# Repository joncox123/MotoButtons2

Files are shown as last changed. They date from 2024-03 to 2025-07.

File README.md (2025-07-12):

# MotoButtons 2
### MotoButtons 2 has reached the initial 2.0 release and is ready for users to build their own unit. You can build this either for a commercial, 5-way IP68 joystick, the part costs $75 USD + shipping, or with the original $2.50 USD Adafruit 504 5-way joystick (as in MotoButtons Lite). However, construction is much easier either way because of the 3D printed Nylon case.

**If you have developed different or improved 3D printed case designs, please let me know via the Issues and I can either link to them here or add them to this repository.**

Please submit any bug reports via the Issues tab on this GitHub repository page.

### Welcome to MotoButtons 2, the low-cost, waterproof, DIY Bluetooth motorcycle controller. Version 2 features many upgrades over [the original](https://github.com/joncox123/MotoButtons):
- 3D printed case with handlebar mount
- Separate RGB LED for indicating modes and status
- Commercial, IP68 5-way (or 4-way) castle joystick ($75 USD + shipping)
  -  or the original $2.50 USD 5-way Adafruit joystick [see alternative case design](./CaseAdafruitJoystick/README.md)
- Three pushbuttons

The target price to order all parts, including the case, is approximately $80 to $100 excluding shipping costs. The main variable is the cost and quality of the 3D printed case. However, the most expensive part is the IP68 rated 5-way joystick. The cheapest available is from Ruffy Controls, although industry prices for similar parts vary from $45 to beyond $300. Lastly, the least expensive service for 3D printing is [Craftcloud](https://craftcloud3d.com/).

## User Documentation
Please see the **[User's Guide](./UsersGuide/README.md)** for instructions on how to use your MotoButtons 2.

## Assembly Steps

[1] Order your 3D printed case by uploading the three CAD STEP files to [Craftcloud](https://craftcloud3d.com/). Choose the Nylon SLA material, not filament PLA.
  - For the Ruffy HS IP68 joystick, [upload these CAD STEP files](./Case/Parts). **NOTE: please wait for a revision of this case that includes 6 screws for the lid and a thicker handlebar clamp before ordering. The Adafruit case version has already been revised.**
  - For the low-cost, Adafruit $2.50 USD 5-way joystick, use [these STEP files](CaseAdafruitJoystick/README.md) for the case instead.

[2] Order the parts from Digikey or Mouser:
  - For the commercial, IP68 5-way joystick from Ruffy Controls, [order from Digikey](https://www.digikey.com/short/hzjjppm1). These parts are also listed in the [Bill of Materials](./Parts/BOM.csv). Note, due to shipping costs, it is cheaper to order several HS joysticks from Ruffy Controls at once. I recommend ordering one for each bike, or organize a group buy on a forum.
  - Using the $2.50 Adafruit 504 5-way joystick (no additional shipping costs), [from Mouser](https://www.mouser.com/ProjectManager/ProjectDetail.aspx?AccessID=e6513e64c0). See the [Bill of Materials](CaseAdafruitJoystick/BOM.csv).

[3] Read the [wiring diagram and construction guide](./ConstructionGuide/README.md) to assemble your MotoButtons 2 after obtaining the parts and the case.

[4] Upload the software to the microcontroller using a USB-C cable and the Arduino program. See [this guide](./Programming/README.md) for detailed instructions.

### A case for the Ruffy 4/5-way joystick
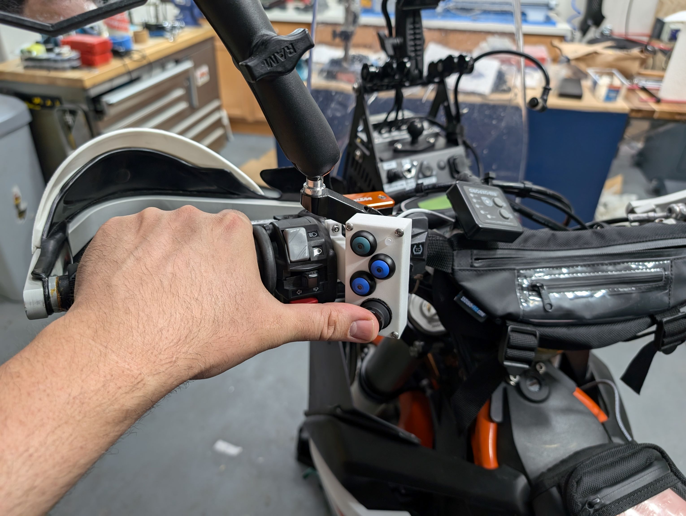
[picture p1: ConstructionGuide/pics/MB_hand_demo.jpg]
Completed unit mounted to bike

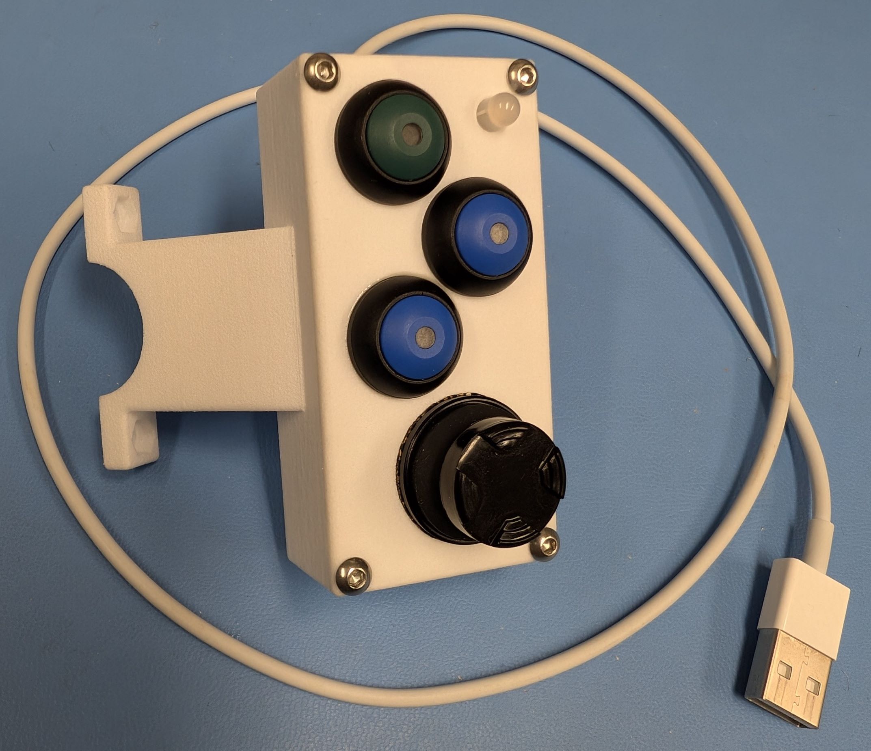
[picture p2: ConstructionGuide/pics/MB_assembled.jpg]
Assembled unit on electrical bench

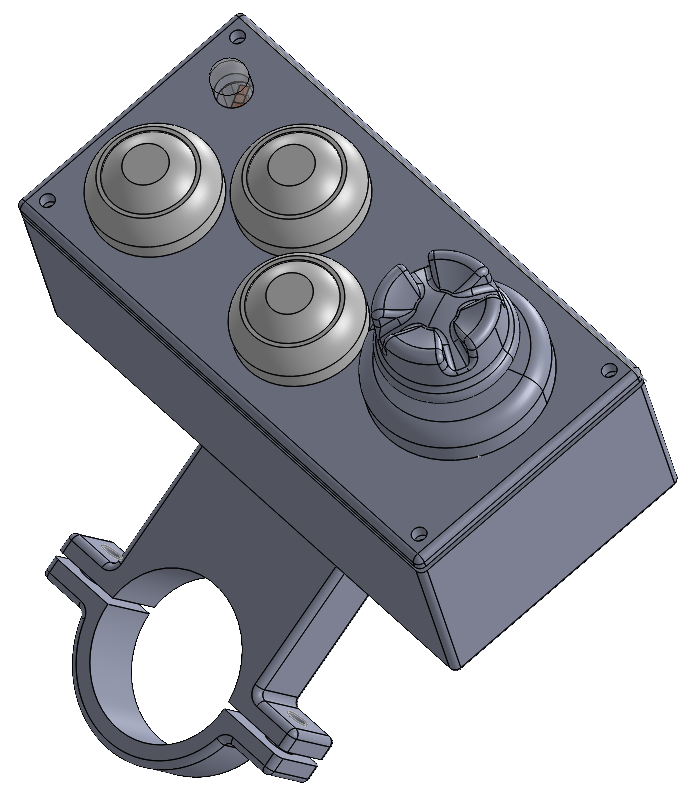
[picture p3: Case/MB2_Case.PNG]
3D Printed Case Model


### A case for the Adafruit 504 $2.50 USD 5-way joystick
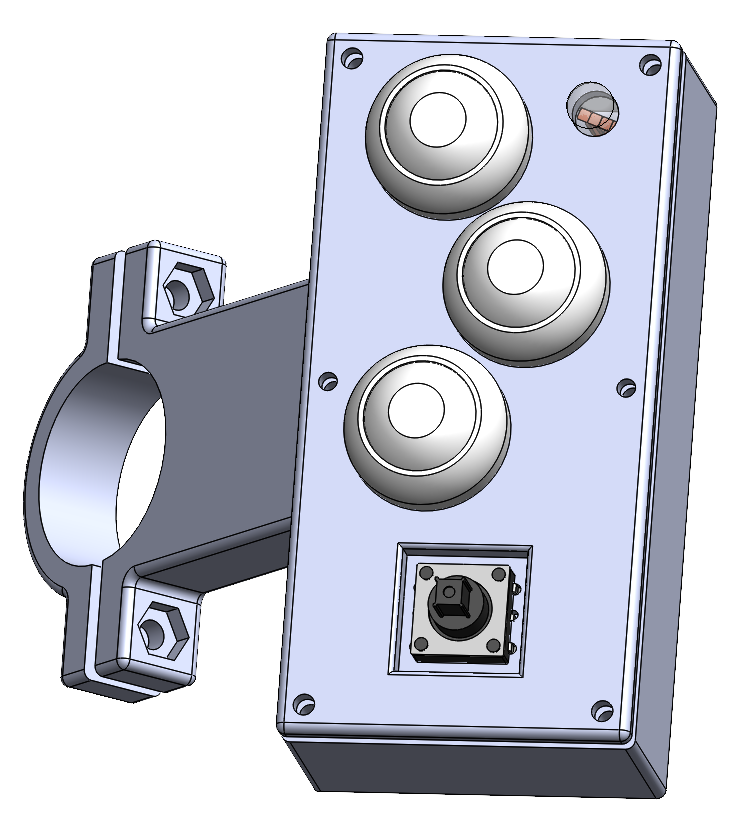
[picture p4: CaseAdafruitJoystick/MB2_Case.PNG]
Low-cost 3D Printed Case Model


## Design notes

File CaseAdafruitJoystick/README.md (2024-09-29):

# An alternative case that uses the very low cost, 5-way Adafruit 504 joystick

[Download the CAD STEP files](Parts) to upload to your 3D printing service.

Case for Adafruit low cost joystick

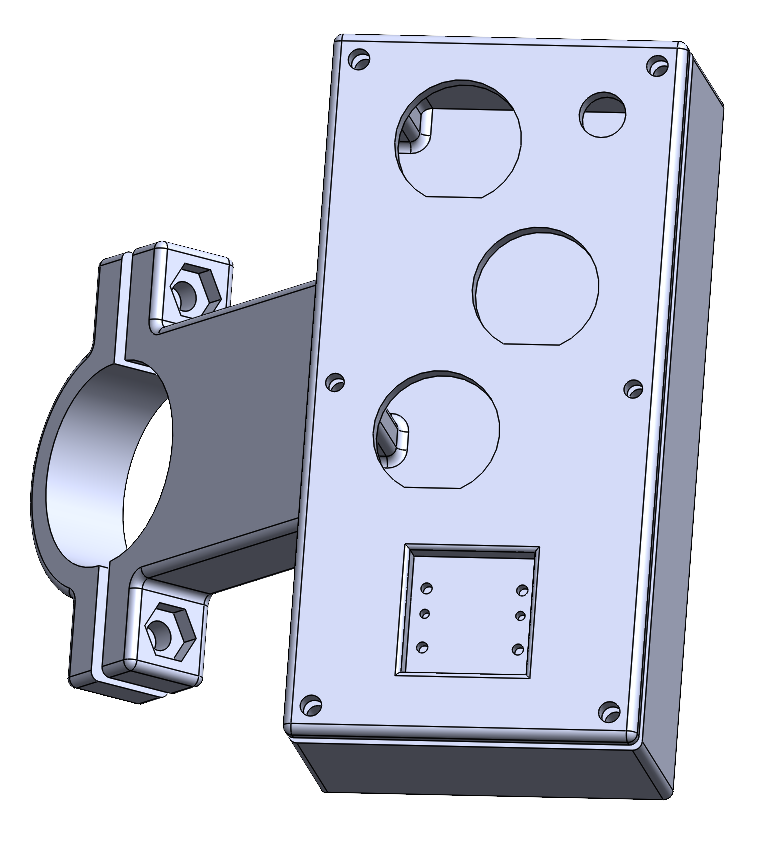
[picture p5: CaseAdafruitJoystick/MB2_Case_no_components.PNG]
Case for Adafruit low cost joystick


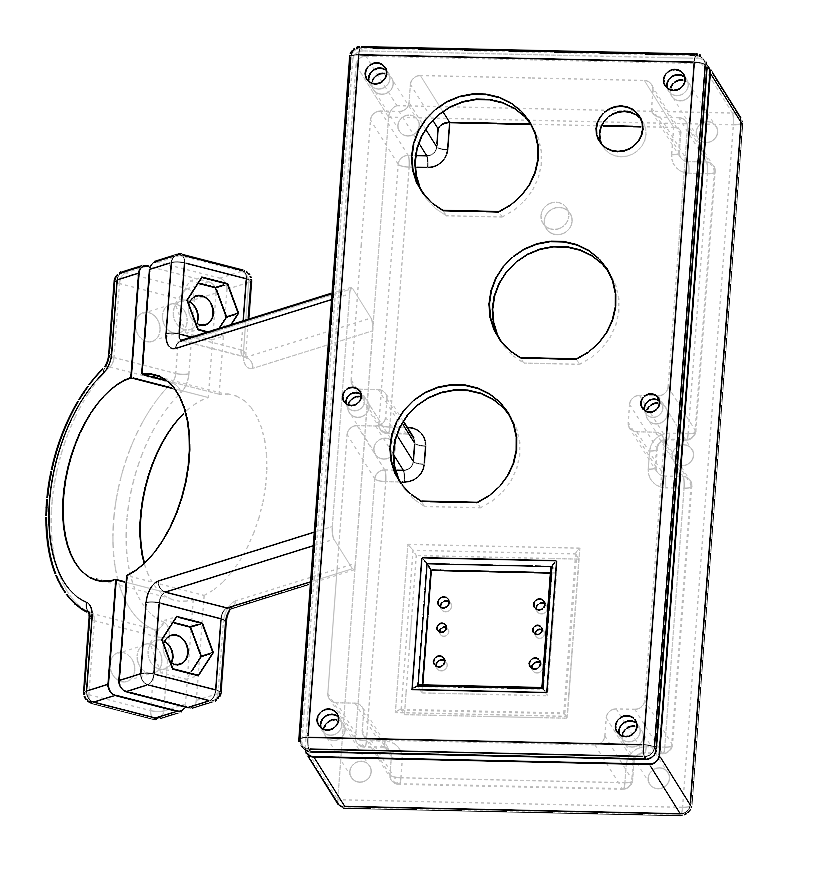
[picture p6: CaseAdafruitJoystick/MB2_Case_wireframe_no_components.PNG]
Case for Adafruit low cost joystick


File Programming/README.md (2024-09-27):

## Upload the Microcontroller Software
The easiest way to do this would be with a custom installer. However, that work is not yet done, so you will need to [download the Arduino IDE](https://www.arduino.cc/en/software), install the support package for the microcontroller, and then upload via a USB cable. The installation steps are [described here.](https://wiki.seeedstudio.com/XIAO_BLE/#getting-started)

First, open the Arduino IDE and then open Preferences in the File menu. Paste the URL (https://files.seeedstudio.com/arduino/package_seeeduino_boards_index.json) to the microcontroller board support package into the "Additional board managers URLs" text field. Click OK. 

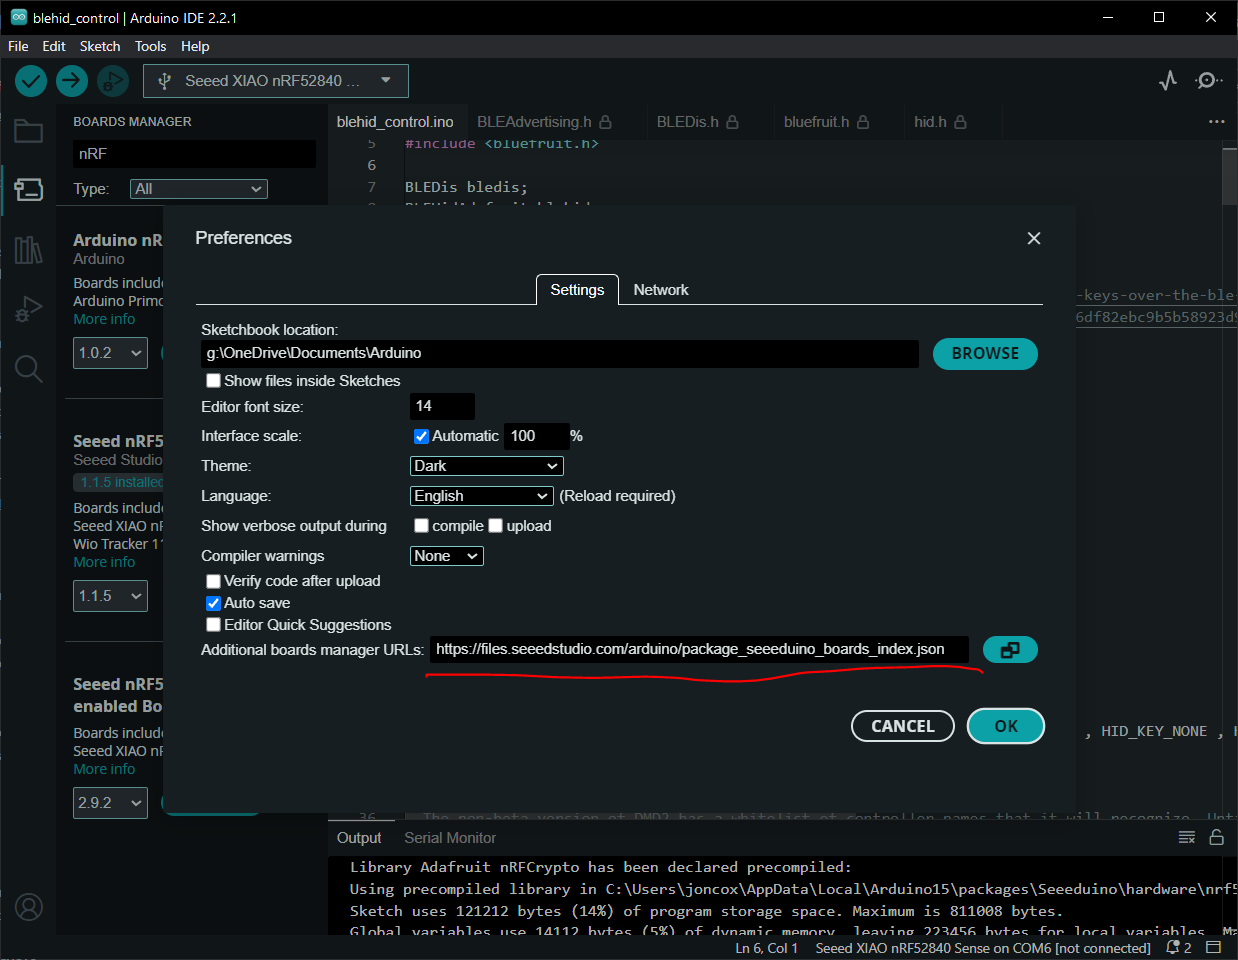
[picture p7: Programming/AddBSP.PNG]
add Seeed BSP


Second, install the Seeed nRF Boards package by clicking on the side button that is second from the top, to open the Board Manager. Type "nRF" into the search field at the top and install the "Seeed nRF52 Boards" package. 

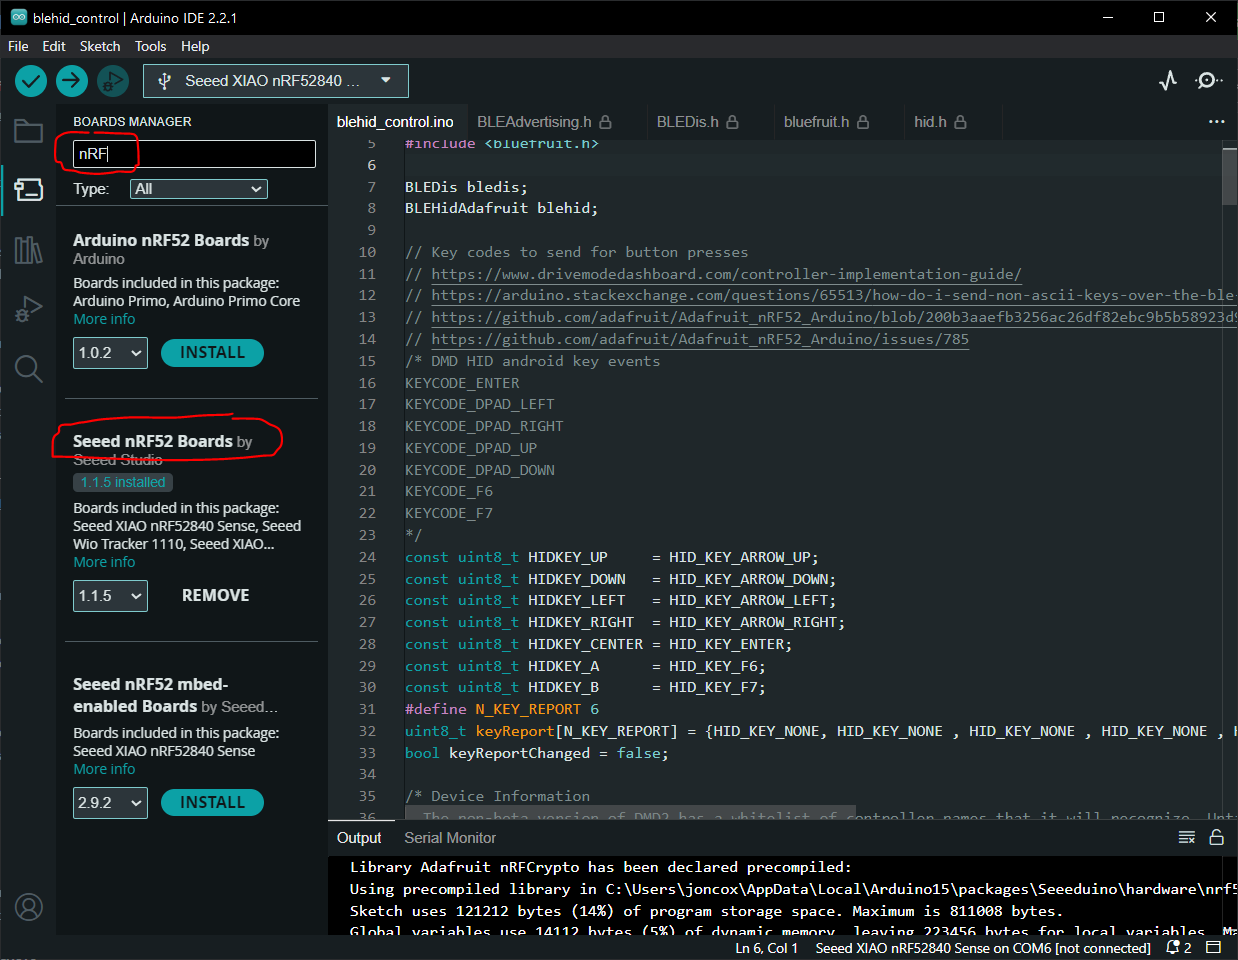
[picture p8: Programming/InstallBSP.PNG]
install Seeed BSP


Third, [download the source code file](../ArduinoCode/MotoButtons2.ino) and open in the Arduino IDE. Attach the microcontroller via a USB-C cable. Select the board that you just attached with the drop down box in the upper toolbar. It should say "Seeed XIAO nRF52840".

Finally, click the upload button!

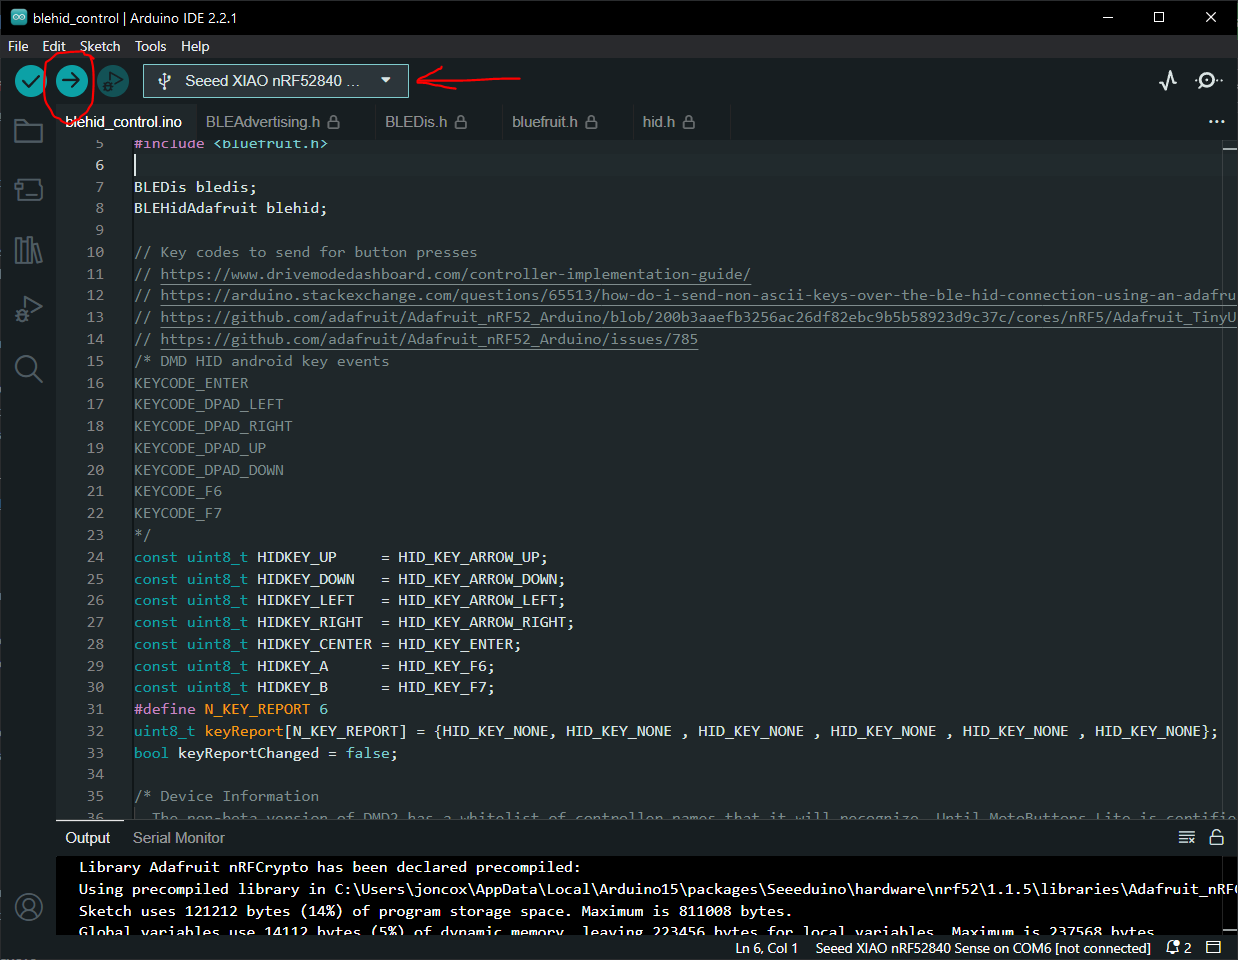
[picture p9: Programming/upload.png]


## Updating the Software for Future Releases
To update the software again, you need to open the case and connect the USB-C port to your computer. Launch the Arduino IDE and open the new source code file. However, there is a bug in the microcontroller's DFU (Device Firmware Update) bootloader that sometimes prevents new software from being uploaded unless a special reset procedure is followed. 

If you try to upload new software and you either get an error stating the DFU upload failed, or it simply times out after about 60 seconds, you probably need to perform the special reset. There are two options to perform this reset. The first option is to hold down buttons A and B for 10 seconds, as if you were changing the mode. This should reset the controller into DFU mode again. The second option is to rapidly double tap the tiny reset button that is next to the USB-C connector. However, this is hard to do because it is so small, and it requires opening the case, which could be impossible if it is filled with epoxy and you can't get to the button. 

After resetting into DFU mode, keep in mind that the COM port (serial port) number of the microcontroller will have changed. So you will need to select it again in the drop down menu in the toolbar at the top of the Arduino IDE. Then you can proceed to upload the new code.

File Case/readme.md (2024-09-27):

# 3D Printed Case Design

To order the case, upload the [.STEP CAD files for the three parts](./Parts) to [Craftcloud](https://craftcloud3d.com/).

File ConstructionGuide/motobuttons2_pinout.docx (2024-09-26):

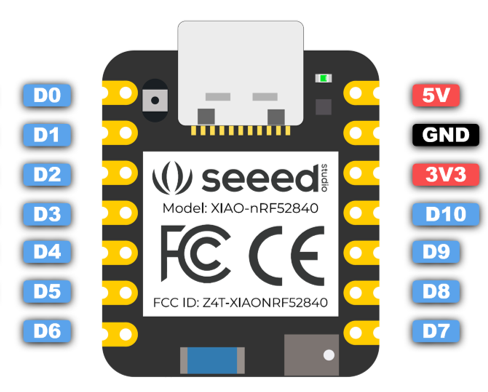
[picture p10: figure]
pir

XIAO nRF52840 Microcontroller Pinout | Button and LED Assignment D0: Joystick RIGHT (X+ / Blue wire) D1: Joystick CENTER/TOP (5-way / Orange wire) D2: Joystick UP (Y+ / Yellow wire) D3: Joystick LEFT (X- / Pink wire) D4: Joystick DOWN (Y- / Grey wire) D5: Button A D6: Button B D7: Button C D8: RGB LED RED D9: RGB LED BLUE D10: RGB LED GREEN

MotoButtons 2 Pinout Data (https://github.com/joncox123/MotoButtons2)

Ruffy HS1 Joystick Pinout Table

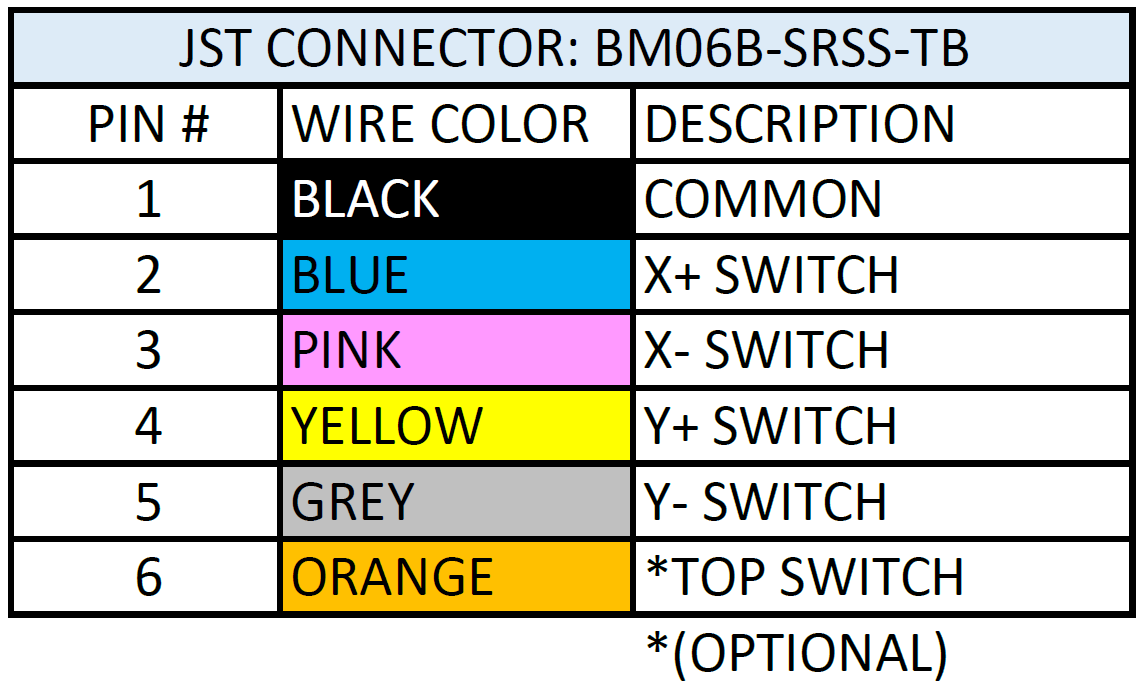
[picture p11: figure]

QT Brightek RGB LED Pinout

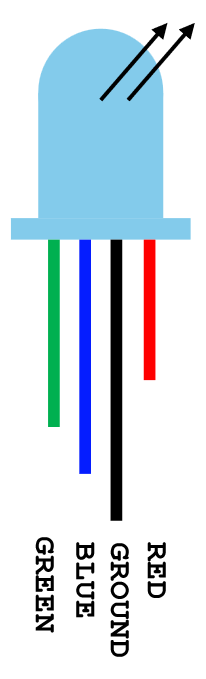
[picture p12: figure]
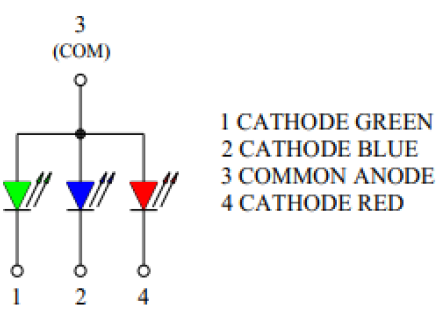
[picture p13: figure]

Simplified Diagram | QBL8RGB60D0-2897

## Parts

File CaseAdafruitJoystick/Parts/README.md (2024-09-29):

Download these CAD STEP files and upload them to Craftcloud to print your 3D case.

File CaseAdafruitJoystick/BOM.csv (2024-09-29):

Mouser # | Mfr. # | Manufacturer | Customer # | Description | Order Qty. | Price (USD) | Ext.: (USD)
485-4697 | 4697 | Adafruit |  | Joysticks Black Rubber Joystick Nubbin Cap for Navigation Joystick | 1 | $0.50 | $0.50
485-504 | 504 | Adafruit |  | Adafruit Accessories Thru-hole 5-way Navigation Switch | 1 | $1.95 | $1.95
713-102010448 | 102010448 | Seeed Studio |  | Bluetooth Development Tools - 802.15.1 Seeed Studio XIAO nRF52840, MicroPython - Bluetooth 5.0 | 1 | $10.38 | $10.38
655-2-2329387-1 | PB6B2FM7M1CAL01 | TE Connectivity |  | Pushbutton Switches PB OFF/ON FC Blue White LED IP68 | 1 | $4.74 | $4.74
655-1-2329387-6 | PB6B2FM6M1CAL01 | TE Connectivity |  | Pushbutton Switches PB OFF/ON FC Green White LED IP68 | 1 | $4.74 | $4.74
655-2-2329387-2 | PB6B2FM7M1CAL03 | TE Connectivity |  | Pushbutton Switches PB OFF/ON FC Blue Red LED IP68 | 1 | $5.98 | $5.98
604-WP154A43VBDZGWCA | WP154A4SEJ3VBDZGW/CA | Kingbright |  | Standard LEDs - Through Hole 5MM RGB LED | 1 | $1.95 | $1.95

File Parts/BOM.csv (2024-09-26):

Index | Quantity | Part Number | Manufacturer Part Number | Description | Customer Reference | Available | Backorder | Unit Price | Extended Price USD
1 | 1 | 2524-HS1-6-ND | HS1-6 | Hat switch, 5-way, castle actuat |  | 1 | 0 | 76.35000 | 76.35
2 | 1 | 1597-102010448-ND | 102010448 | SEEED STUDIO XIAO NRF52840 |  | 1 | 0 | 9.96000 | 9.96
3 | 1 | 1516-QBL8RGB60D0-2897-ND | QBL8RGB60D0-2897 | LED RGB DIFFUSED T-1 3/4 T/H |  | 1 | 0 | 1.22000 | 1.22
4 | 1 | EG4961-ND | RP8100B1M1CEBLKGRNNIL | SWITCH PB SPST-NO 0.125A 125V |  | 1 | 0 | 4.63000 | 4.63
5 | 1 | EG4958-ND | RP8100B1M1CEBLKBLUNIL | SWITCH PB SPST-NO 0.125A 125V |  | 1 | 0 | 4.63000 | 4.63
6 | 1 | EG4960-ND | RP8100B1M1CEBLKYELNIL | SWITCH PB SPST-NO 0.125A 125V |  | 1 | 0 | 4.63000 | 4.63

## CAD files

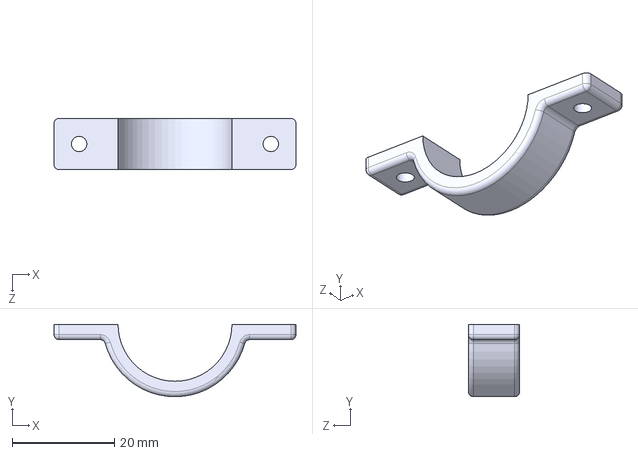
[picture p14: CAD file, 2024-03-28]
Case/Parts/bottom-clamp.STEP
47.2 x 14.1 x 10.0 mm

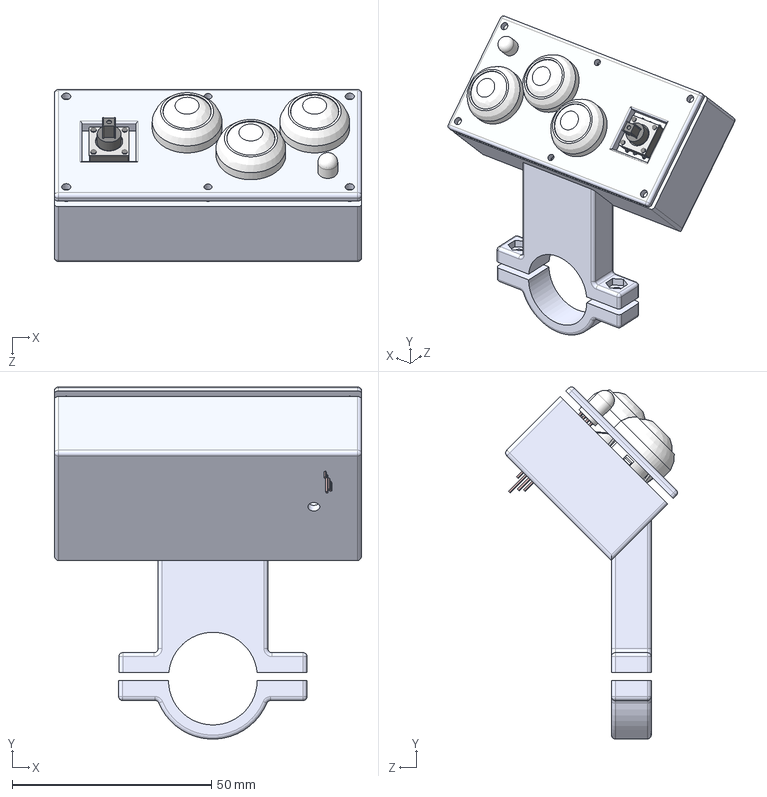
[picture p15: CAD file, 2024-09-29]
CaseAdafruitJoystick/MB2_Case.STEP
77.1 x 88.2 x 43.1 mm
hb_mount_top
hb_mount_bottom
case-bottom
rp8100b1m1ceblkxxxnil x 3
Part 5.step
Part 2.step
Part 4.step
Part 6.step
Part 3.step
Joystick_504

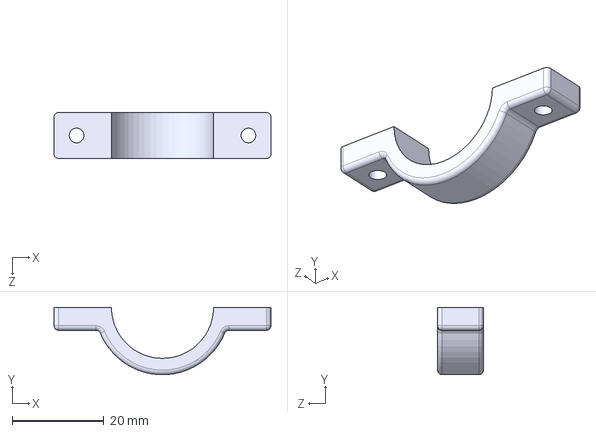
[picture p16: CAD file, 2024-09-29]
CaseAdafruitJoystick/Parts/clamp.STEP
47.2 x 14.7 x 10.0 mm

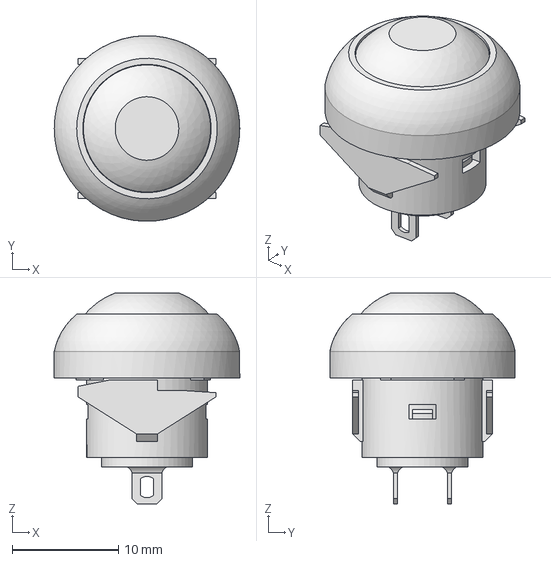
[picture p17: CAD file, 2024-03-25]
Parts/Buttons/RP8100B1M1CEBLKxxxNIL.stp
17.5 x 17.5 x 19.9 mm

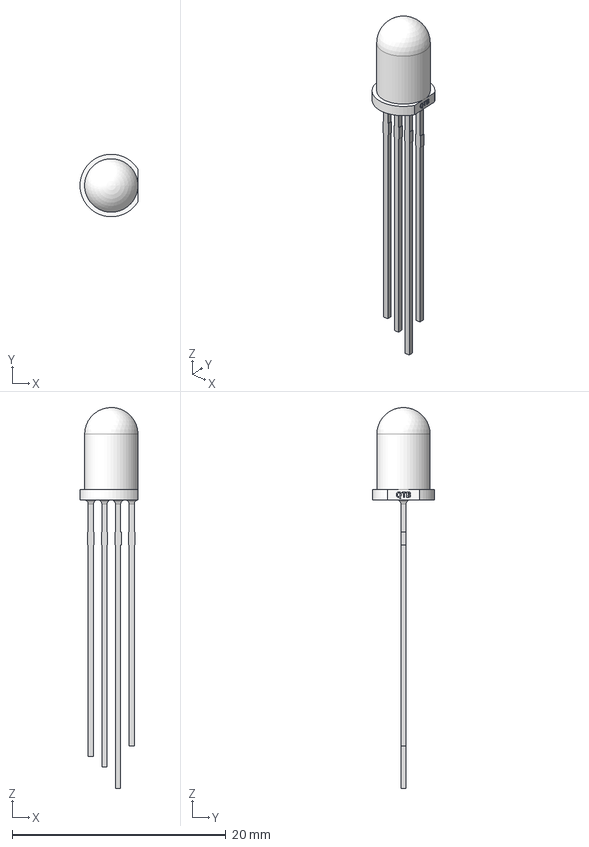
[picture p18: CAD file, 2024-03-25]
Parts/LED/QBL8RGB.step
5.43 x 5.85 x 35.7 mm

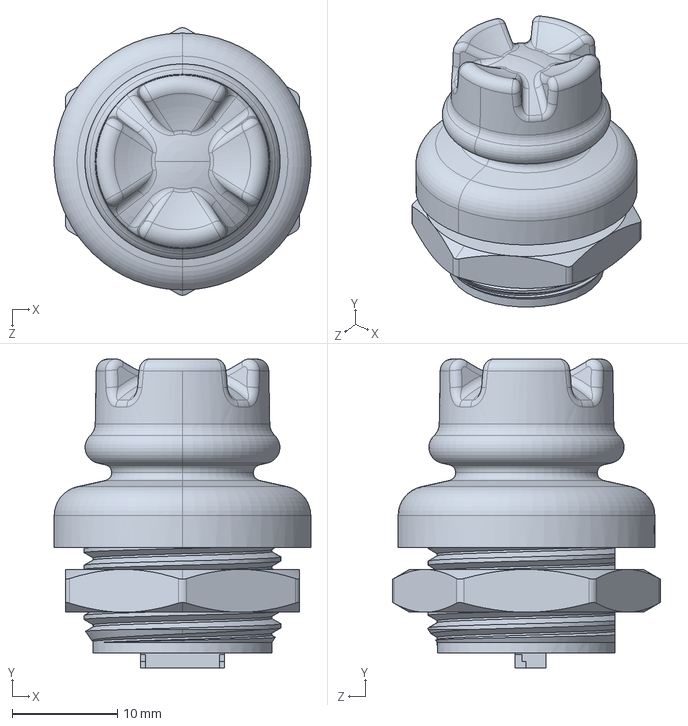
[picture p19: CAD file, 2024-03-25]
Parts/Ruffy-Joystick/hs1-48.SLDPRT
24.4 x 29.3 x 25.4 mm

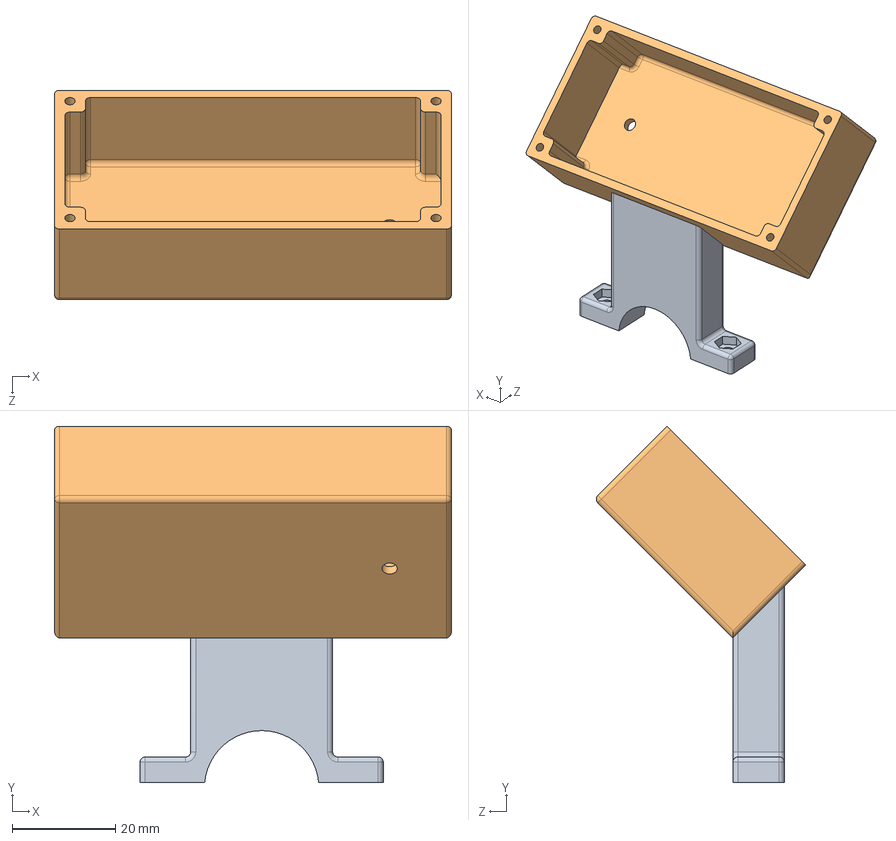
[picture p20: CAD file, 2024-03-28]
Case/Parts/case-bar.STEP
77.1 x 69.2 x 40.7 mm
hb_mount_top
case-bottom

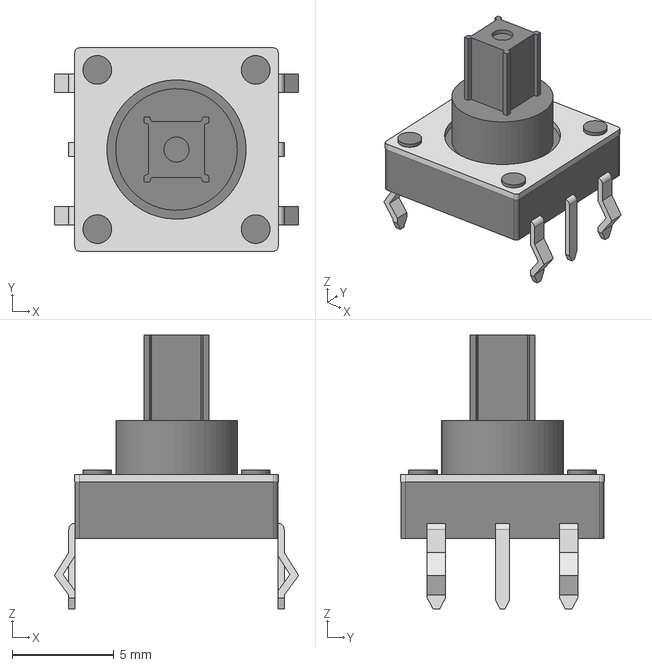
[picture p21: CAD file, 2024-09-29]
CaseAdafruitJoystick/Joystick_504.stp
12.0 x 10.0 x 13.5 mm

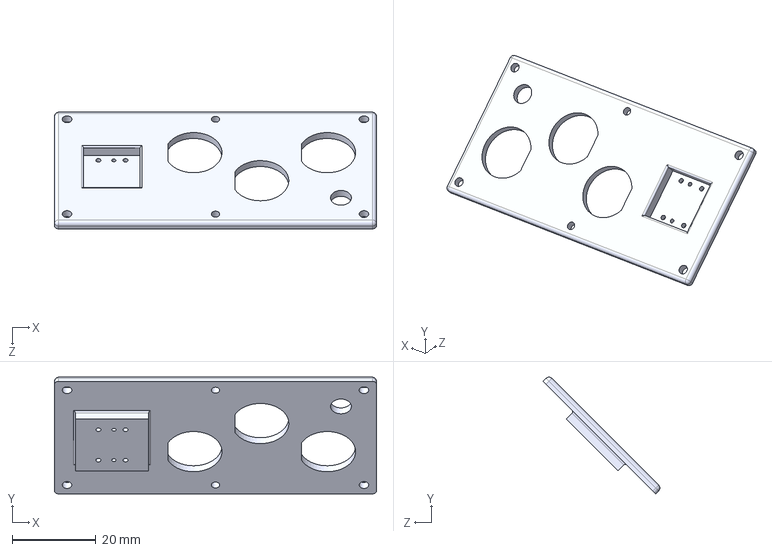
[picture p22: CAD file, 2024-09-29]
CaseAdafruitJoystick/Parts/lid.STEP
77.1 x 27.9 x 27.9 mm

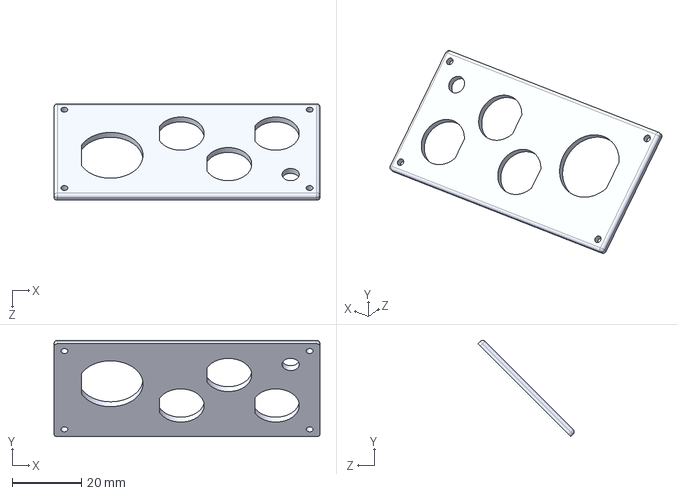
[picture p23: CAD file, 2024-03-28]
Case/Parts/lid.STEP
77.1 x 27.9 x 27.9 mm

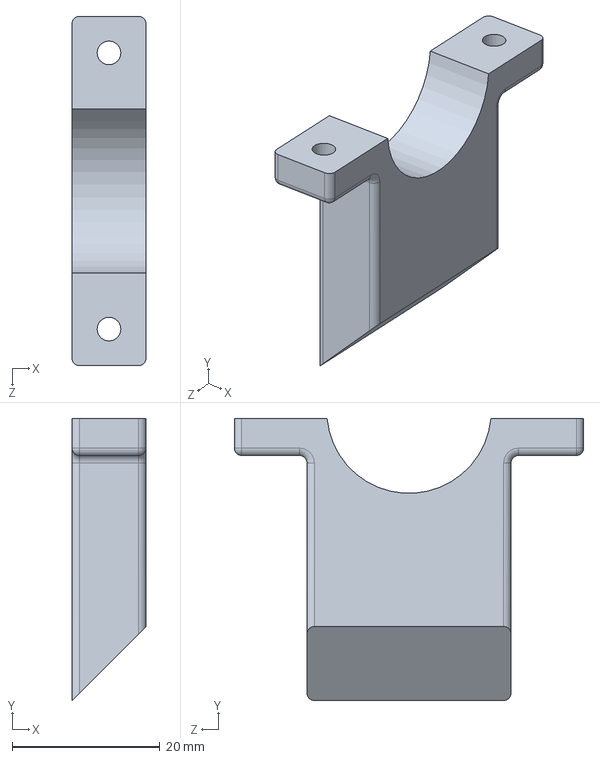
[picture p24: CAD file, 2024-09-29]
CaseAdafruitJoystick/hb_mount_top.SLDPRT
10.0 x 38.1 x 47.2 mm

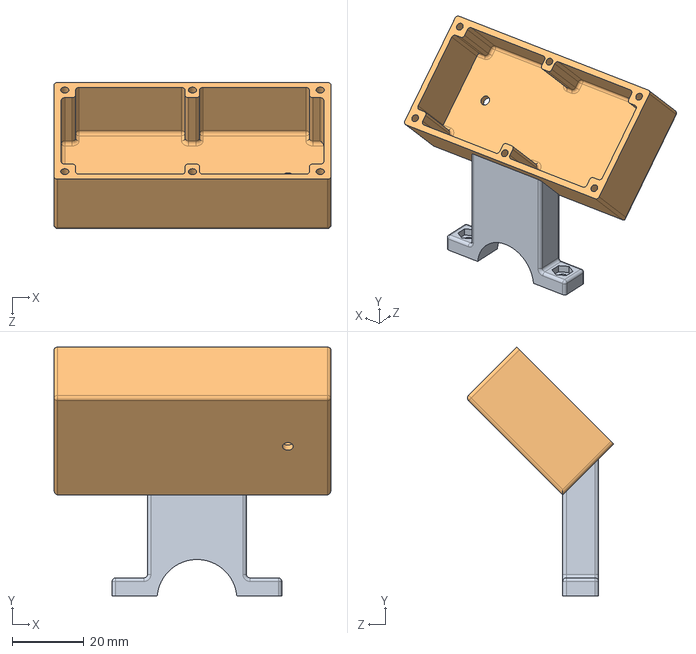
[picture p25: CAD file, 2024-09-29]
CaseAdafruitJoystick/Parts/case.STEP
77.1 x 69.2 x 40.7 mm

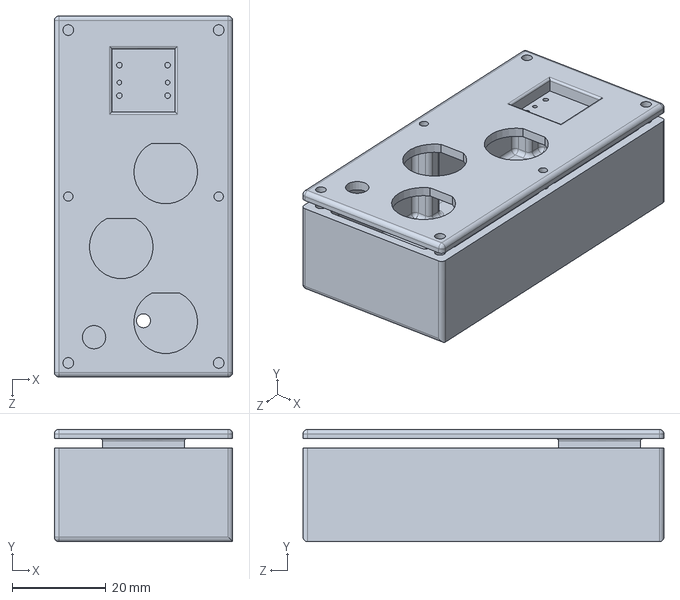
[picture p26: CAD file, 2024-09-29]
CaseAdafruitJoystick/case-bottom.SLDPRT
38.1 x 24.0 x 77.1 mm

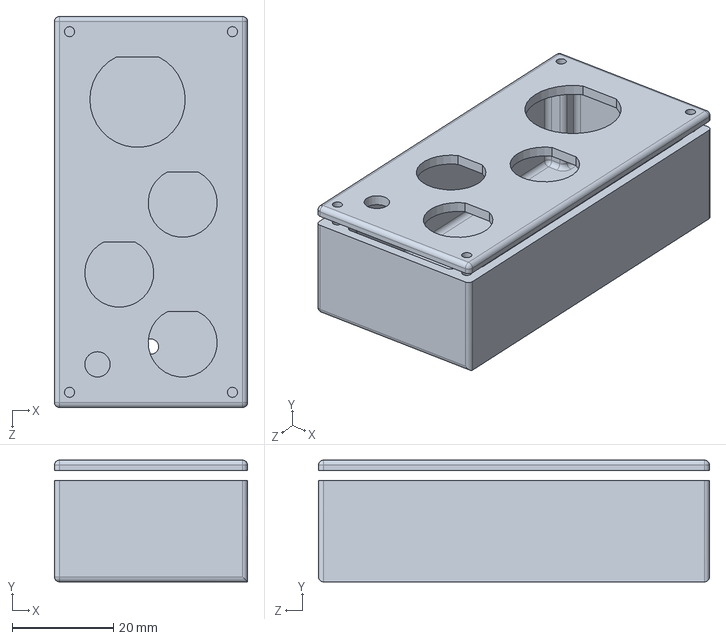
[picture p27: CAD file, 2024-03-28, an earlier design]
Case/case-bottom.SLDPRT
38.1 x 24.0 x 77.1 mm

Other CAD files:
CaseAdafruitJoystick/hb_mount_bottom.SLDPRT
Case/MB2_Case.STEP
Case/hb_mount_top.SLDPRT
Case/hb_mount_bottom.SLDPRT
Case/MB2_Case.SLDASM
CaseAdafruitJoystick/Joystick_504.SLDPRT
CaseAdafruitJoystick/MB2_Case.SLDASM
CaseAdafruitJoystick/MB2_Case.SLDDRW
Parts/Buttons/rp8100b1m1ceblkxxxnil.SLDPRT
Parts/LED/QBL8RGB.SLDASM
Parts/Ruffy-Joystick/HS1-48.IGS

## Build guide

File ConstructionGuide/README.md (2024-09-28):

### Construction Guide 
Prior to assembly, you will need the following hardware to complete construction:
- Four M3x0.5 10 mm stainless button head screws (available at most Ace, TrueValue or similar hardware stores in the USA)
- Two M3x0.5 12 mm stainless button head screws
- Two M3 stainless lock nuts (stop nuts)
- Two M3 stainless washers
- A M3x0.5 tap for threading the holes in the case
- A #40 0.098-in (2.5 mm) drill bit for "tapping" (threading) the case holes
- A #31 0.120-in (3.00 mm) drill bit for creating "clear holes" in the case lid for the lid screws
- A piece of insulting electrical tape
- Some silicone RTV sealant (either clear or color matching to your case)
- 22 AWG or finer insulated wire
- An old USB cable (smaller diameter cable preferred) to provide 5V power to the MCU.

## Wiring Diagram
Please print out the [PDF wiring diagram](./Wiring_Diagram_MotoButtons2.pdf) prior to construction.

MotoButtons 2 Wiring Diagram

## Construction
Solder up the buttons, joystick, LED and MCU using 22 AWG or finer gauge wire. Find an old USB cable and cut one end off. The red and black (or uninsulated) wires should be the positive (5V) and ground wires, but please check this with a multimeter and USB charger prior to soldering! **Note: The buttons and LED are connected to the 3.3V output on the MCU, NOT the 5V pin!** Connecting the 5V supply to any other pins on the MCU will destroy it. 
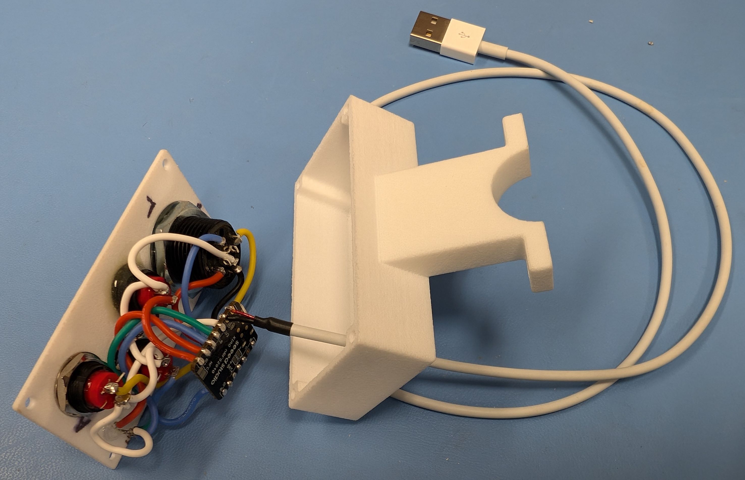
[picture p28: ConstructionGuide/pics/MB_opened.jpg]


You can solder all of the wires to the top of the MCU, except the 5V USB power can be soldered from the bottom.
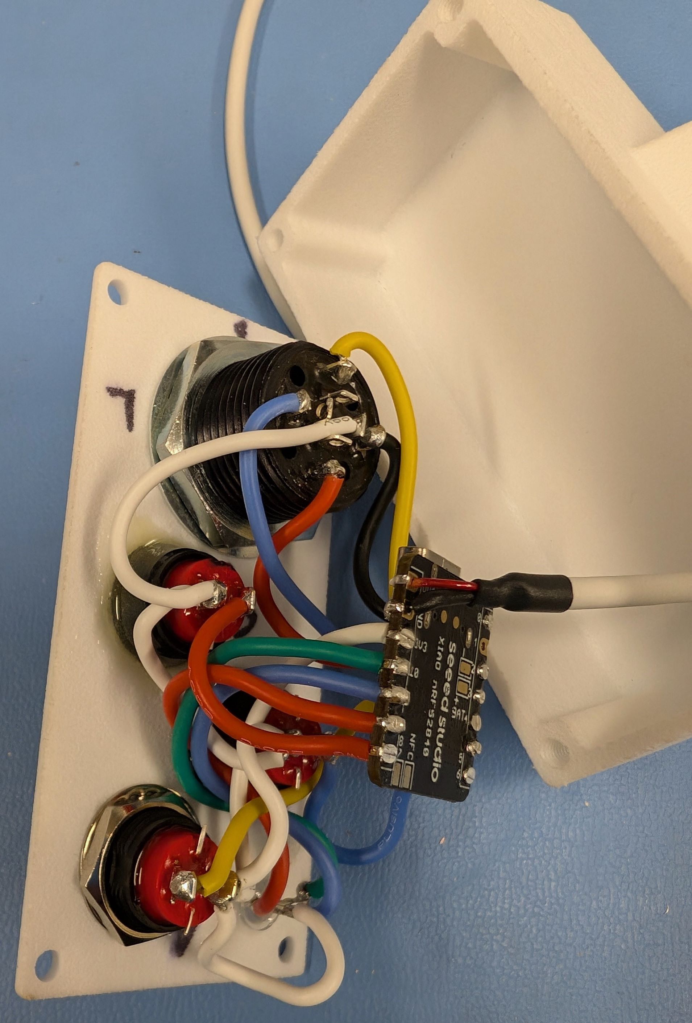
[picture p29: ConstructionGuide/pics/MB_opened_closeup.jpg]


Push the cut end of a USB cable through the hole in the back of the case. It is recommended to use a flexible, small diameter USB cable. However, depending on the diameter, you may need to drill the hole larger. **Ensure that the hole remains a tight fit such that the cable forms a very snug seal when pulled through the hole.**
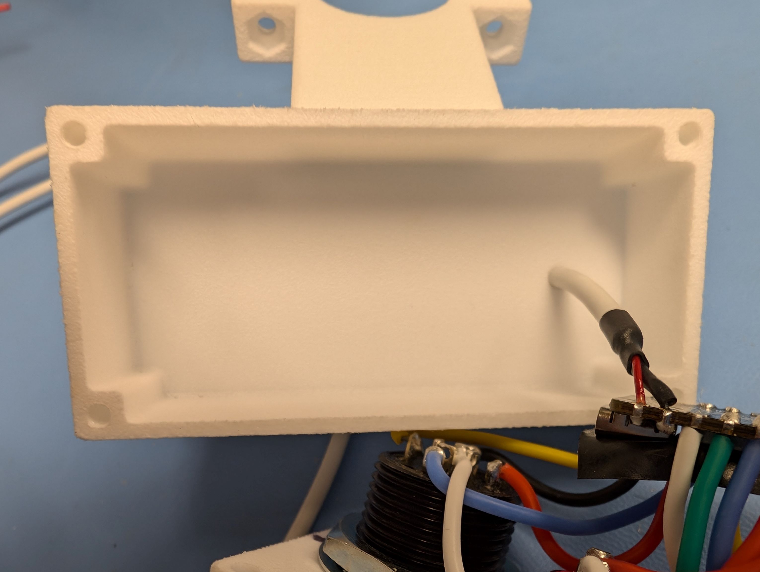
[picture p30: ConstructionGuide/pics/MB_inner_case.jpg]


After soldering, apply some insulating tape (such as electrical tape) around the top of the MCU so that it does not make contact with any of the terminals on the buttons.
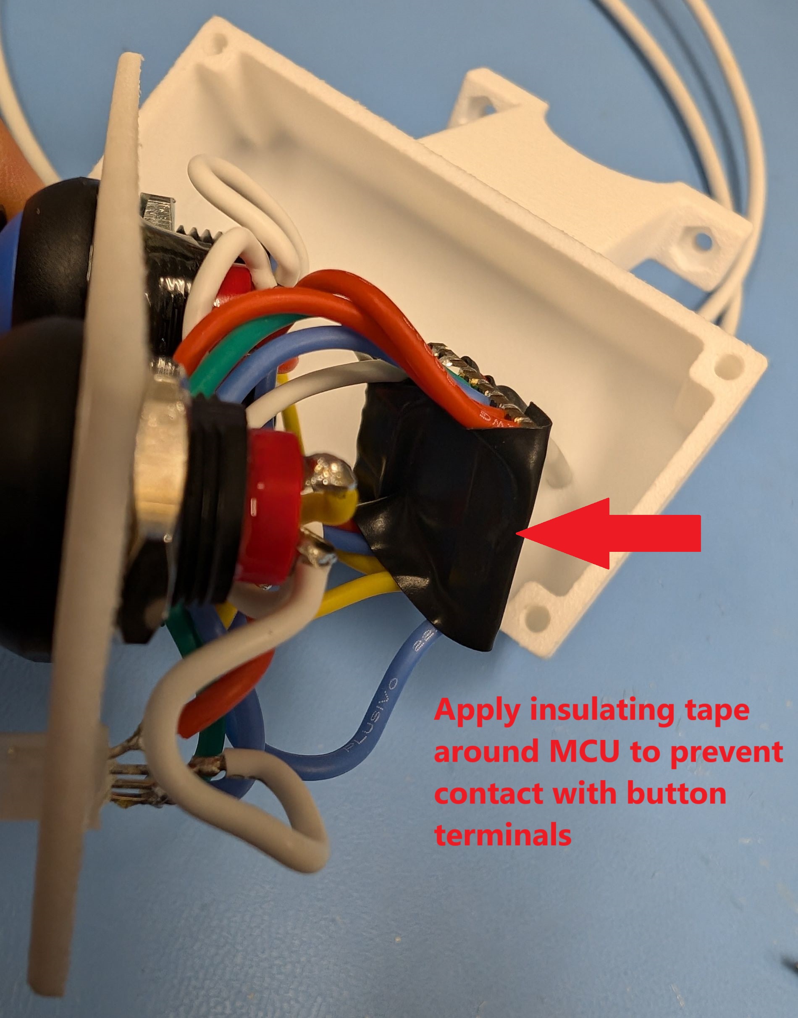
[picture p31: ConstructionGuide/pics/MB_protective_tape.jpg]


The fully assembled unit will look as shown below. You will need to drill the top plate for **M3 screw** clear holes, #31 0.120-in US drill bit or 3.00 mm metric. Also, drill the blind holes in the case body with a #40 0.098-in (2.5 mm) drill bit, being careful not to drill through the case. Then tap the holes carefully with a **M3x0.5 metric tap.** Use 10 mm long M3x0.5 stainless screws to secure the lid to the case. **Make sure not to over torque the screws** or you will strip the plastic threads. You can use a bit of blue Loctite to keep the screws secure.

Finally, sealant can be applied around the lid to waterproof the case, but please remember to **program the MCU prior to final assembly.** You should also use something removable like silicone RTV, so that you can update the firmware. Use color matching or clear sealant and wipe off the excess after assembly. Let it fully cure before handling.
Assembled unit

## Mounting

The unit is mounted to standard 22 mm handlebars between the switchgear and the left mirror/clutch lever mount. You will need to insert a thin piece of rubber or non-slip sheet (such as the liner for kitchen drawers or toolboxes) to go between the case's clamp and the handlebar.
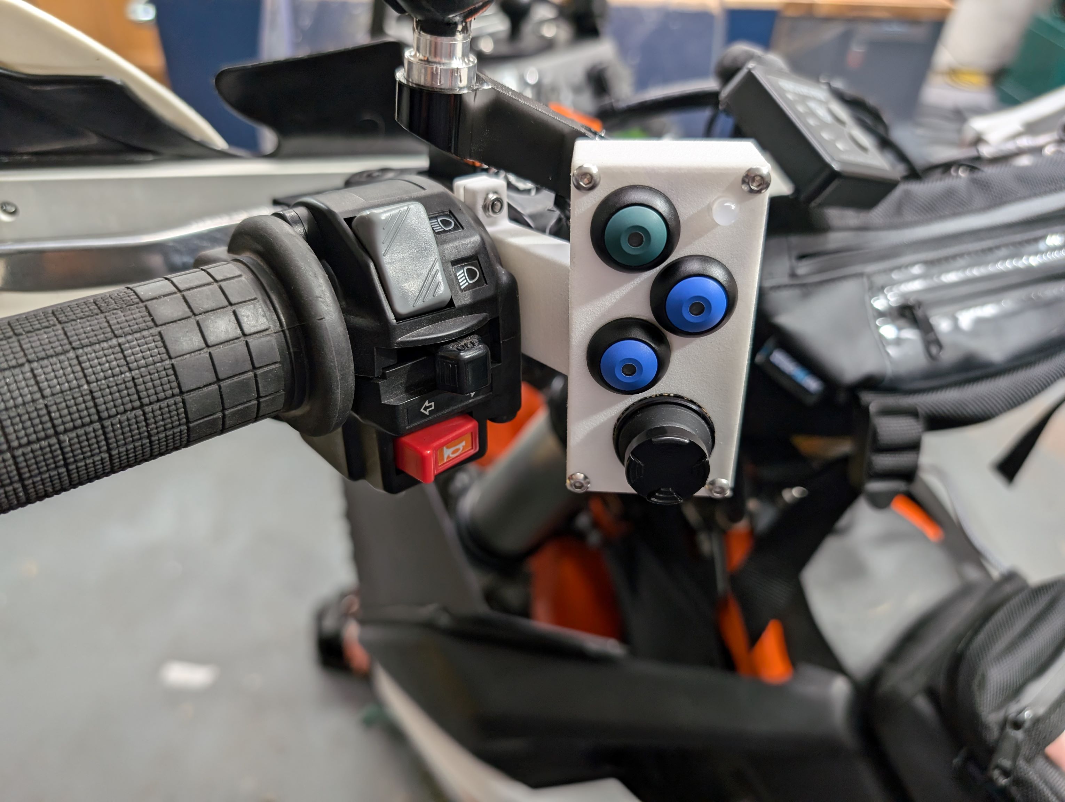
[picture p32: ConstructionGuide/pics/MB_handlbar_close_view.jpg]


Use 12 mm M3x0.5 metric screws and a M3 lock nut (stop nut) to secure the clamp to the case. The M3 nuts will go in the hex shaped holes on the case side, but it can help to put a little glue or grease on them to keep them from falling out while you thread the screws from the clamp side. Tighten only until the mount does not easily move--do not overtighten.
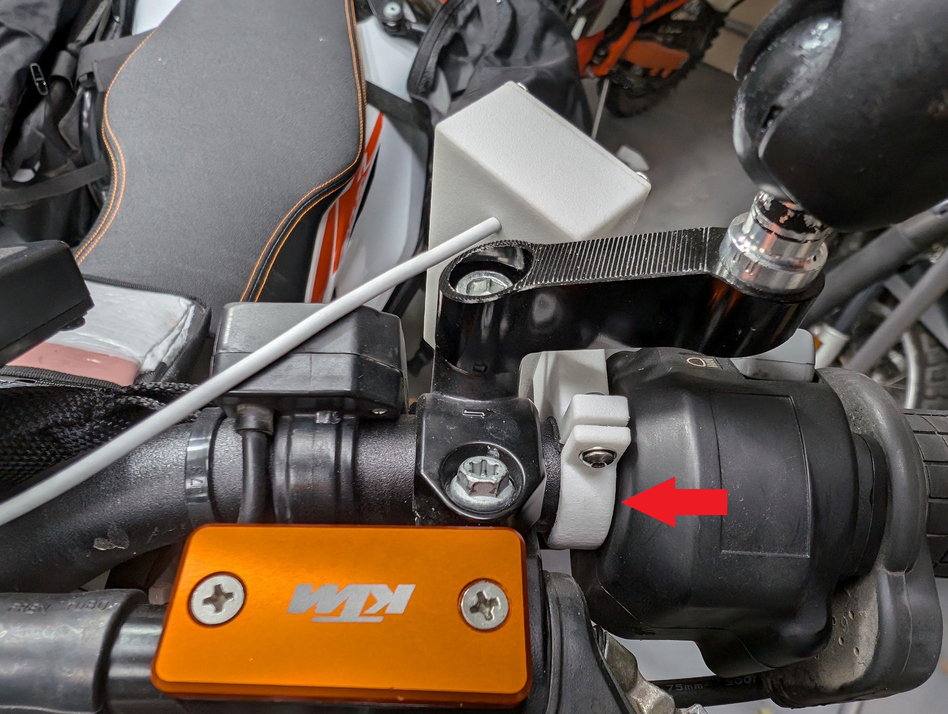
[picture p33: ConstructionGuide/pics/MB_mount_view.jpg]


When mounting is complete, you should be able to activate the controls without fully releasing your grip from the handlebar, depending on your hand size.
Assembled unit

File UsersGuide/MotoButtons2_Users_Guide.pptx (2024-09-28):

## MotoButtons 2 User’s Guide

September 27, 2024

## Device Overview

LED Interpretation

Color | Meaning
Red | 1. Initial power on 2. Virtual button activated 3. (Flashing) Controller orientation changed at power on
White | Power on completed Keypress (optional)
Blue | Solid: Bluetooth enabled Flashing: Bluetooth searching for connection
Green | Mouse mode
Yellow | DMD2 Mode
Cyan | MyRouteApp mode
Magenta | Media player mode

All buttons (except joystick directional input) activate when released, not when pressed!

Color (RGB) mode, action and state indicator LED

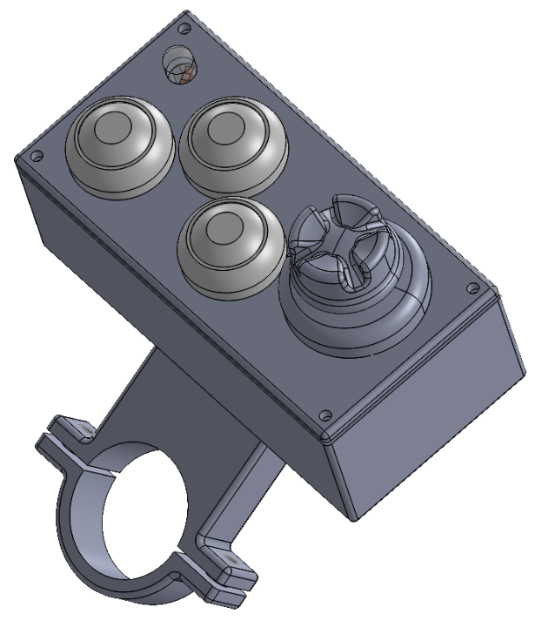
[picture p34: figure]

Long press “C” to activate additional “virtual button”

4-way or 5-way (center button) joystick

A

B

C

5V DC power (from USB cable)

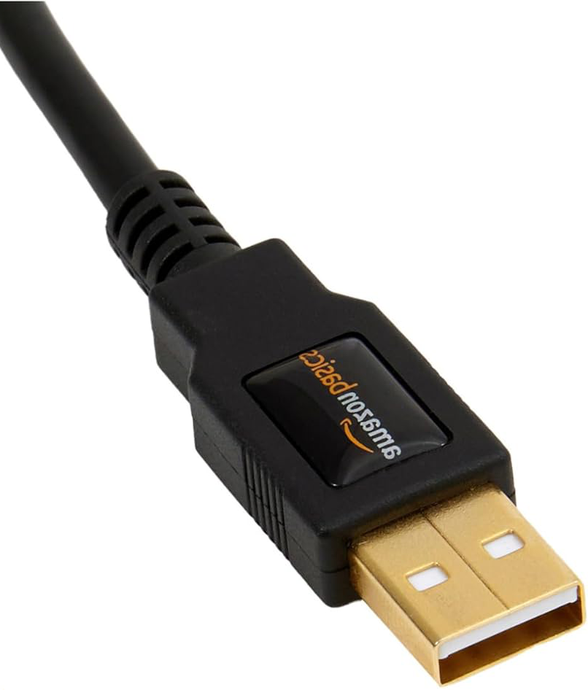
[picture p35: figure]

## Changing the Installation Orientation

Depending on how you choose to install the unit, you may need to set the orientation of the device. This way, “up” on the joystick will be “up” on your phone or tablet.
Setting the orientation
Hold the joystick UP before applying power. Release once the LED flashes RED.
The setting will be stored for future power cycles.

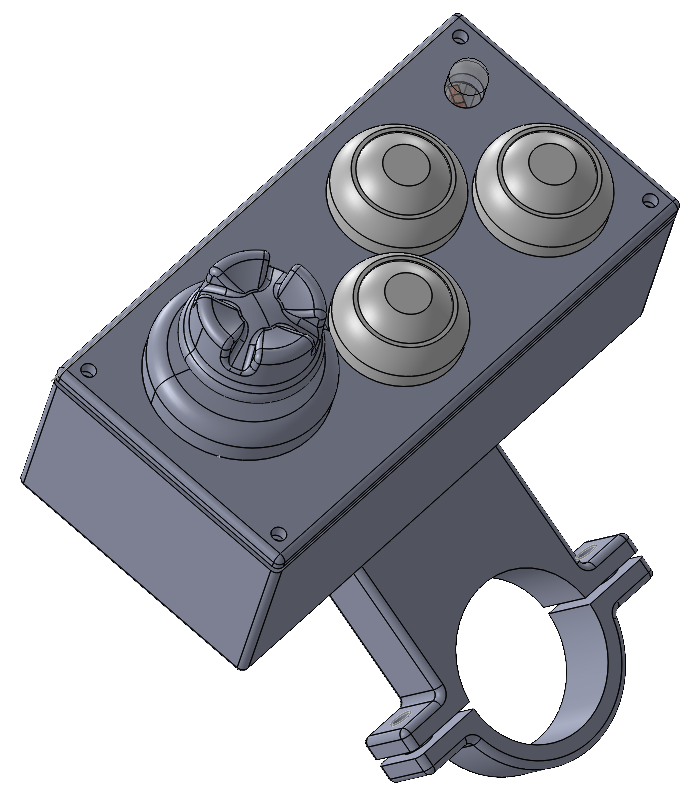
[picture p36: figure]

## Changing the Mode

You can change the mode at any time by long pressing two buttons.
Changing the mode
Holding both the A and B buttons for 1 second. When the mode changes, the LED will cycle to the next color.
The device remembers the mode during power cycles.

Hold both buttons (A and B) for 1 second

A

B

C

DMD2

Mouse

MyRouteApp

Media Player

## Activating the Virtual Button (4-way joysticks)

To accommodate controllers with only a 4-way joystick (no center press), button C can be held down (long press) to simulate the center click of the joystick.
Virtual joystick center press
Hold down Button C for 1 second. The LED will turn RED, then release the button.

A

B

C

Hold “C” down for 1 second to simulate joystick center press

## Mouse Mode

Joystick
Hold up, down, left, right to move cursor.
Press center for mouse or finger press (5-way only).
Holding longer than half a second moves cursor rapidly.
Button C
Mouse or finger press (necessary for 4-way joysticks).

A

B

C

Press for finger tap (click)

Move pointer

## DMD2 Mode

Joystick
Press for enter or change direction/page.
Button A
F6 key
Button B
F7 key
Button C
Enter
Long press: F5 key

A

B

C

F6

F7

Enter (F5 long press)

Enter

Direction/ page

## Media Player Mode

Joystick
Up/down: increase/decrease music volume
Left/right: previous/next track
Center press: mute music
Button A
Play or pause music
Button B
Stop music
Button C
Increase display brightness
Long press: Mute music

Play or pause music

Stop music

A

B

C

Increase brightness (mute long press)

Mute

Change track

Adjust volume

## MyRouteApp Mode

Joystick
Pan map or change field.
Center press: operate compass
Button A
Zoom in
Button B
Zoom out
Button C
Open menu
Long press: start navigation

A

B

C

Zoom in

Zoom out

Enter
(start navigation long press)

Operate compass

Direction/ pan map

## Reprogramming the Firmware

Due to a bug in the Seeed XIAO microcontroller (MCU), a special button combination is necessary to put the MCU in firmware upload mode. This is known as “DFU” mode.
Entering DFU mode
1. Connect the USB-C port on the MCU to a computer.
2. Simultaneously hold down buttons A and B for 10 seconds until the LED goes out.
3. The MCU enters DFU mode. Select the other / new COM (serial) port in the Arduino IDE and click the upload firmware button.

Hold buttons A and B for 10 seconds (until LED goes out)

A

B

C

2. Select the other COM port for firmware upload

3. Click upload button

## Issues, Suggestions or Questions?

If you encounter issues, have suggestions or other questions, please submit an “issue” in the GitHub repository page.
https://github.com/joncox123/MotoButtons2/issues
Alternatively, you may ask the community for help on the ADV Rider forum. However, bugs or issues must be submitted to the GitHub issue tracker.
ADV Rider (https://www.advrider.com/f/threads/28-waterproof-controller-with-joystick-for-myroute-app-and-drivemode-dashboard.1680535)MotoButtons (https://www.advrider.com/f/threads/28-waterproof-controller-with-joystick-for-myroute-app-and-drivemode-dashboard.1680535) Forum (https://www.advrider.com/f/threads/28-waterproof-controller-with-joystick-for-myroute-app-and-drivemode-dashboard.1680535)
Unfortunately, the author cannot respond directly to e-mails.

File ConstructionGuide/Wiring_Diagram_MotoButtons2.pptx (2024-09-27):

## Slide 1

5V Power
(e.g. USB Cable)

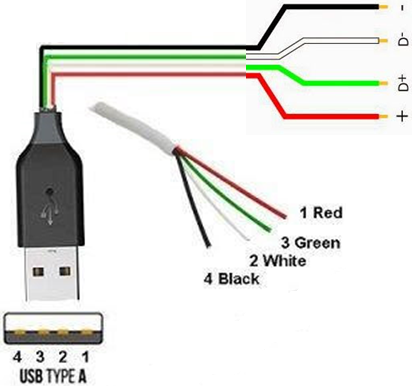
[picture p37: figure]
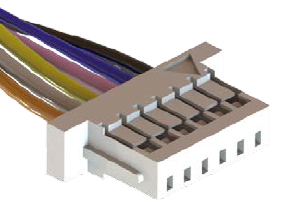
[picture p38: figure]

Ruffy HS1 Joystick
Connector

MotoButtons2 Wiring Diagram (https://github.com/joncox123/MotoButtons2)

https://github.com/joncox123/MotoButtons2

RGB LED

pir

3.3V (NOT 5V !)

A

D0: Joystick RIGHT (X+ / Blue) D1: Joystick CENTER/TOP (5-way / Orange*) D2: Joystick UP (Y+ / Yellow) D3: Joystick LEFT (X- / Pink) D4: Joystick DOWN (Y- / Grey) D5: Button A D6: Button B D7: Button C D8: RGB LED RED D9: RGB LED BLUE D10: RGB LED GREEN

*5-way / Center wire is optional

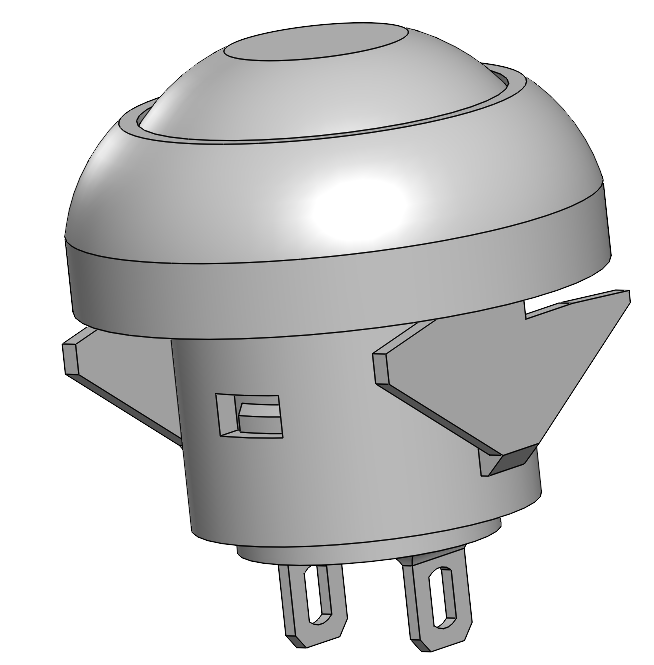
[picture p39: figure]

B

C

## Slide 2

GREEN

BLUE

GROUND

RED

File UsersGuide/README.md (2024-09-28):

# MotoButtons 2 User's Guide

Please download and read the [User's Guide PDF document](./MotoButtons2_Users_Guide.pdf)

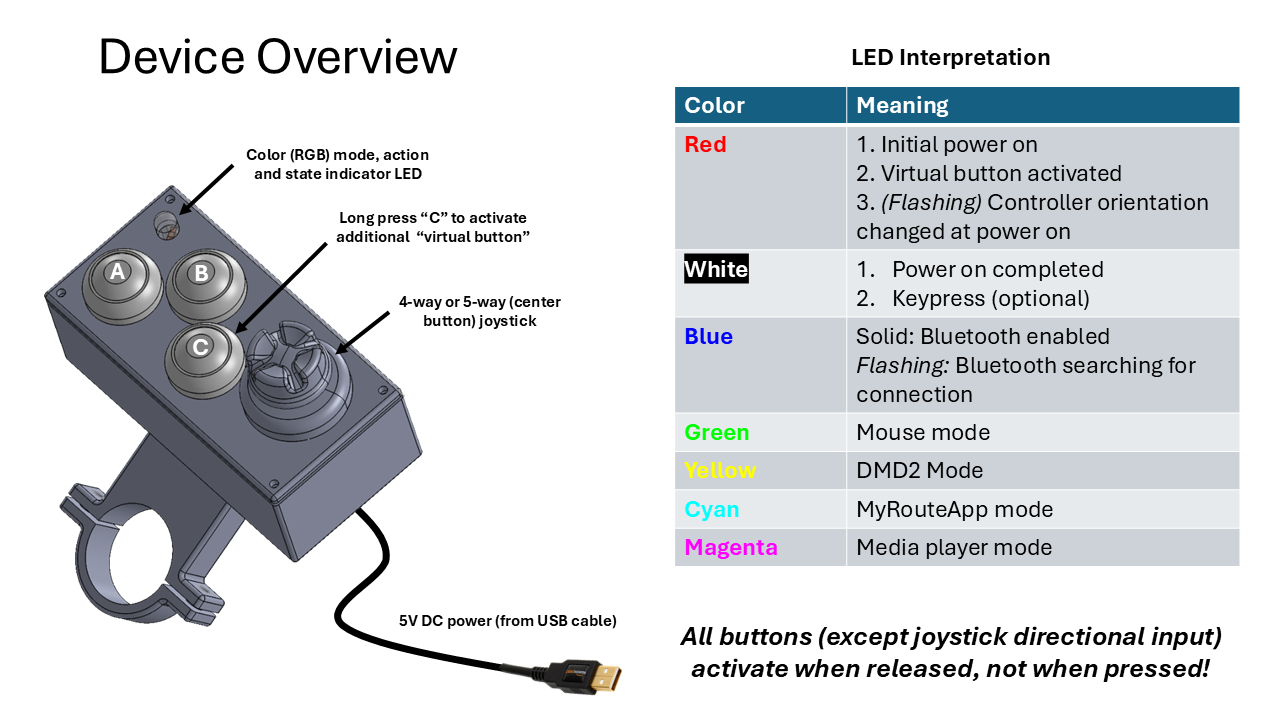
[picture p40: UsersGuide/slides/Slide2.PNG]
Slide 2


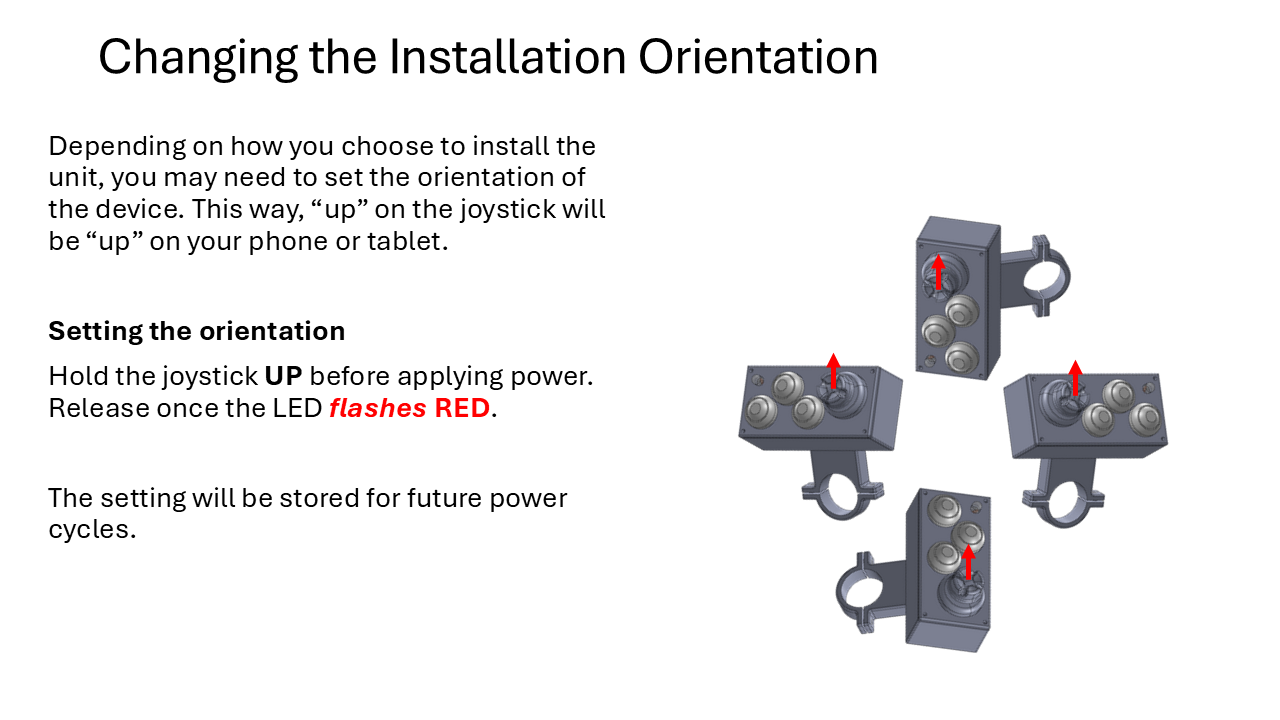
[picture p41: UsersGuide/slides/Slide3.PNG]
Slide 3


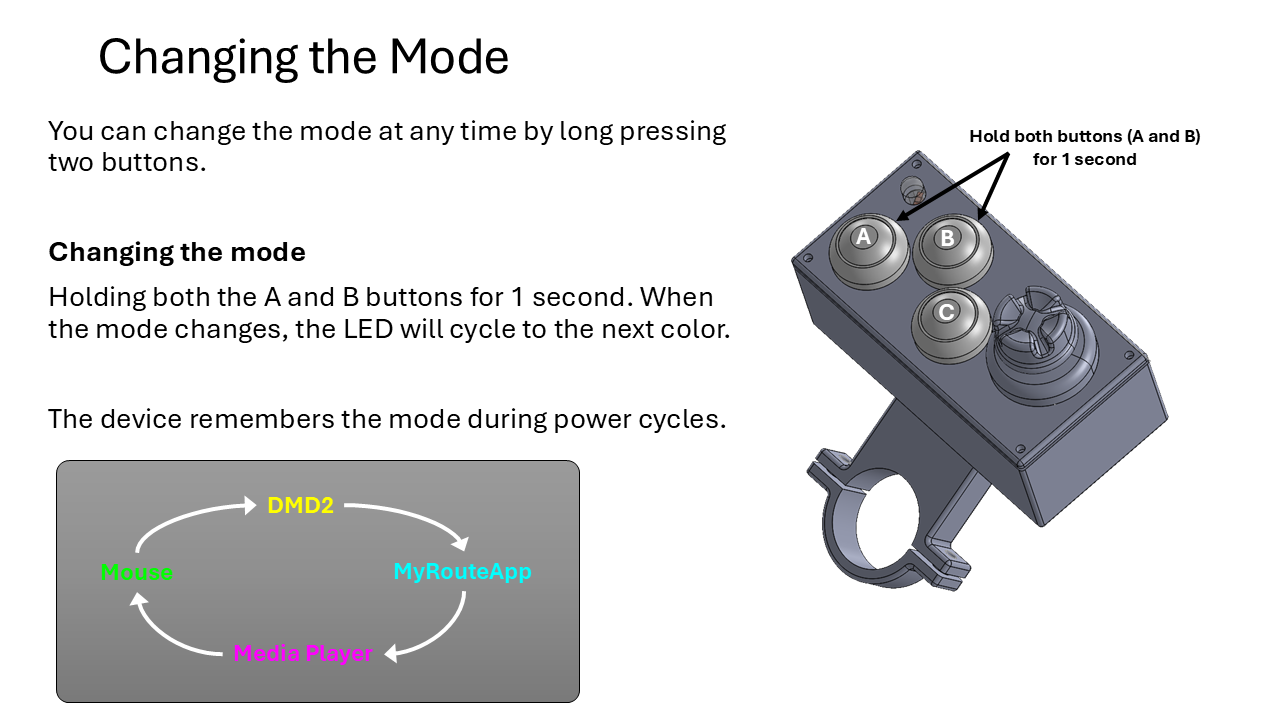
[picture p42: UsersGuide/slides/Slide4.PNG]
Slide 4


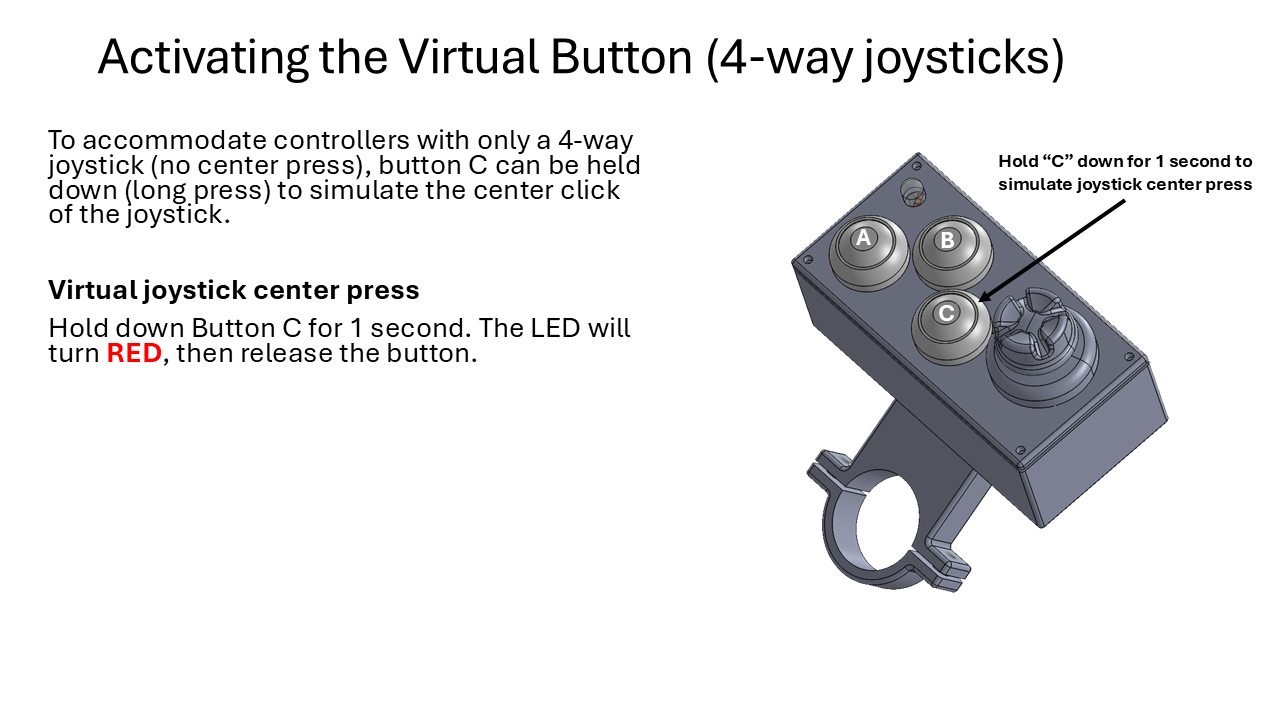
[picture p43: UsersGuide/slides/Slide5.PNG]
Slide 5


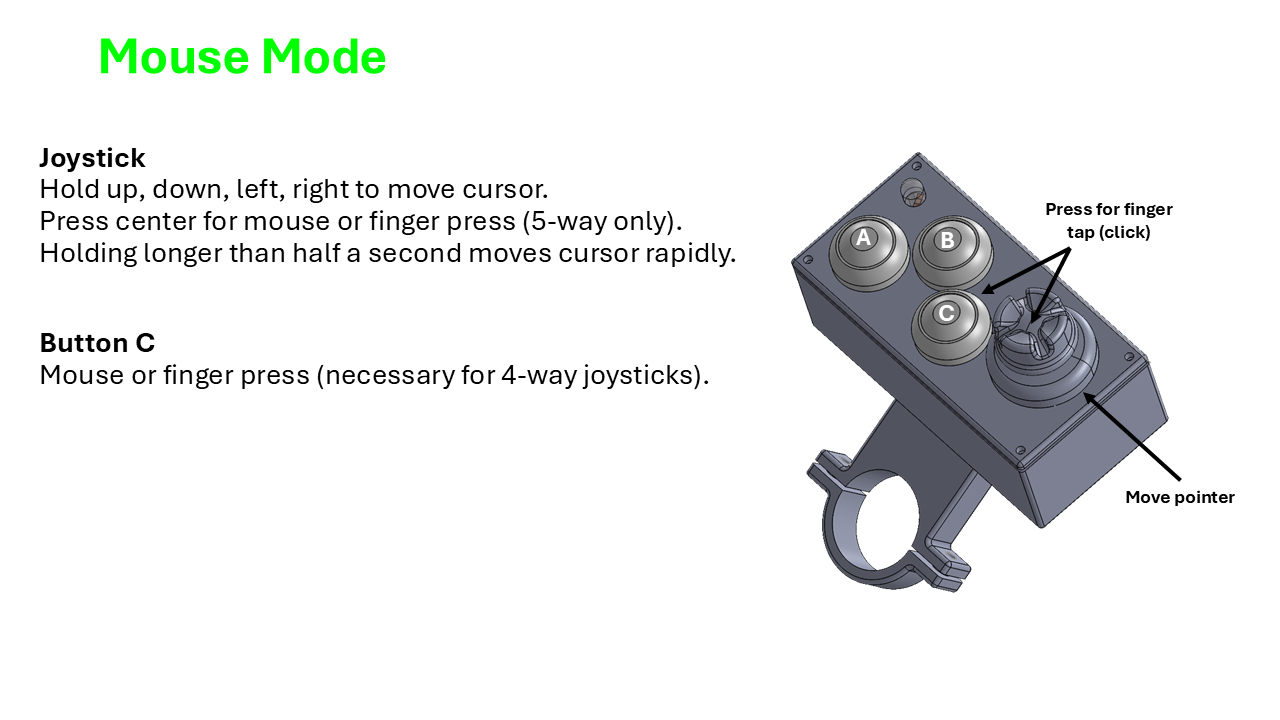
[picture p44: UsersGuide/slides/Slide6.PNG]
Slide 6


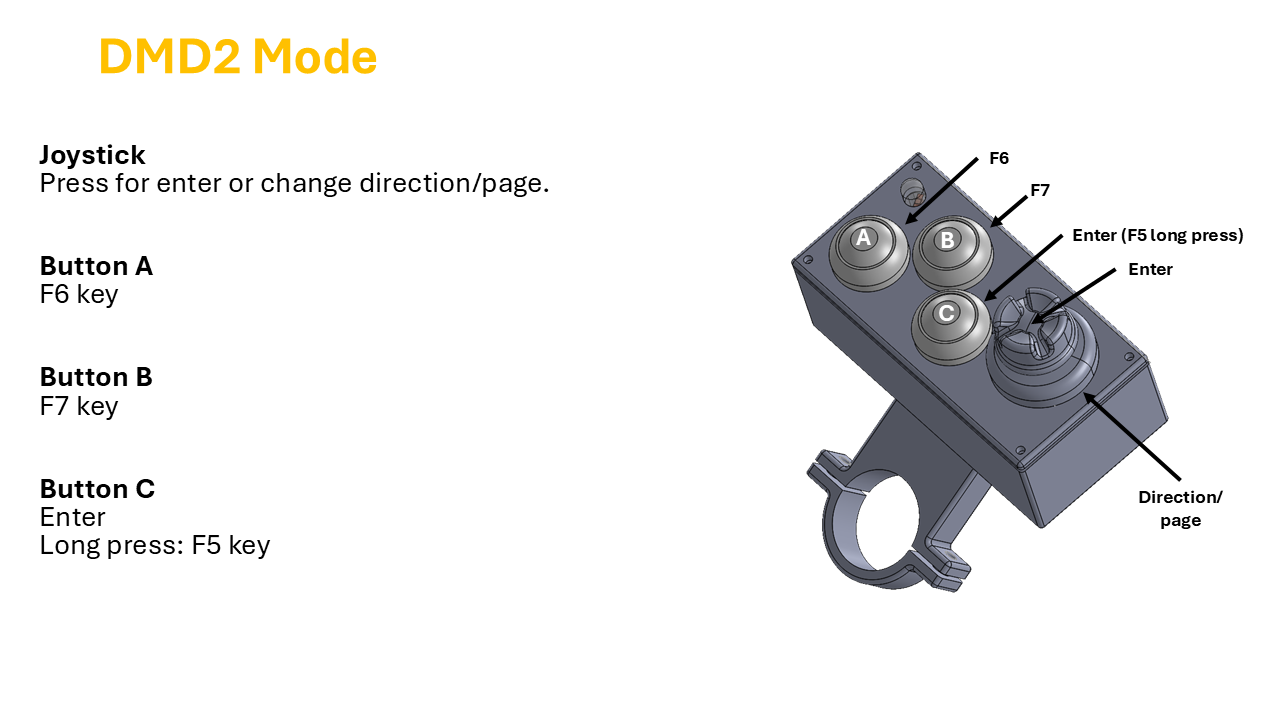
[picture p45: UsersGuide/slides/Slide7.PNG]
Slide 7


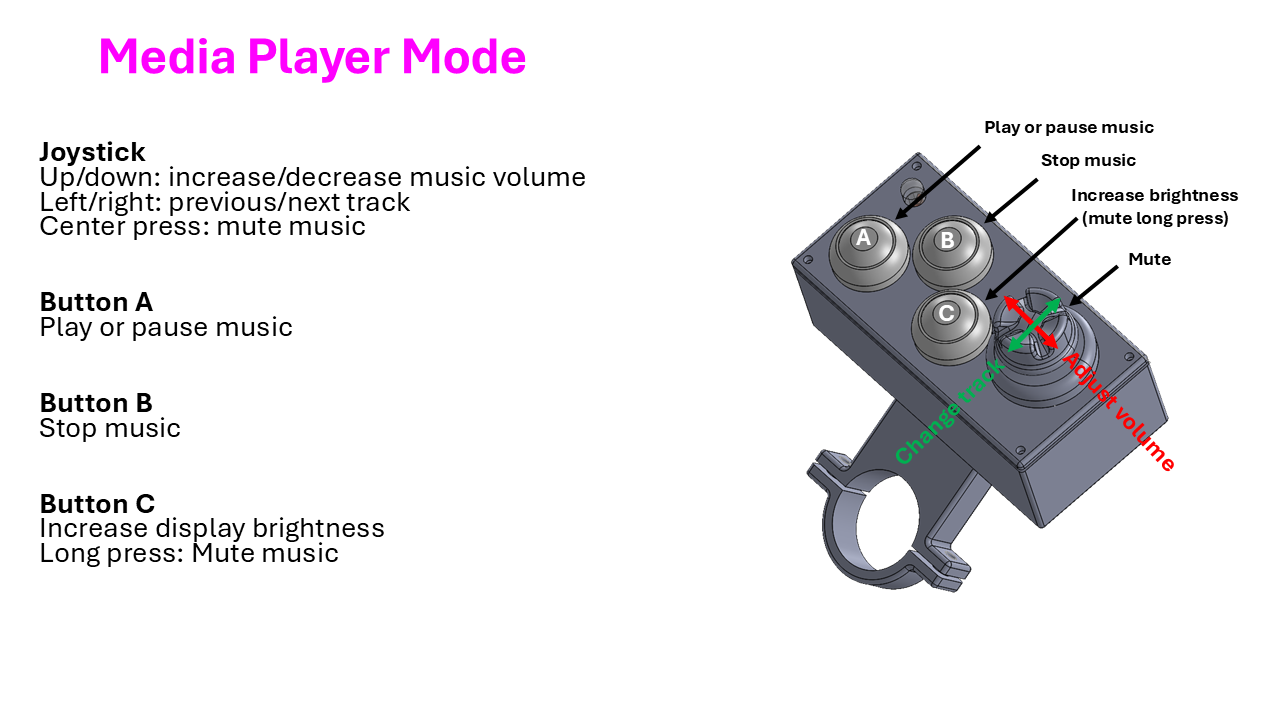
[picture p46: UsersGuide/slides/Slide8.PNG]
Slide 8


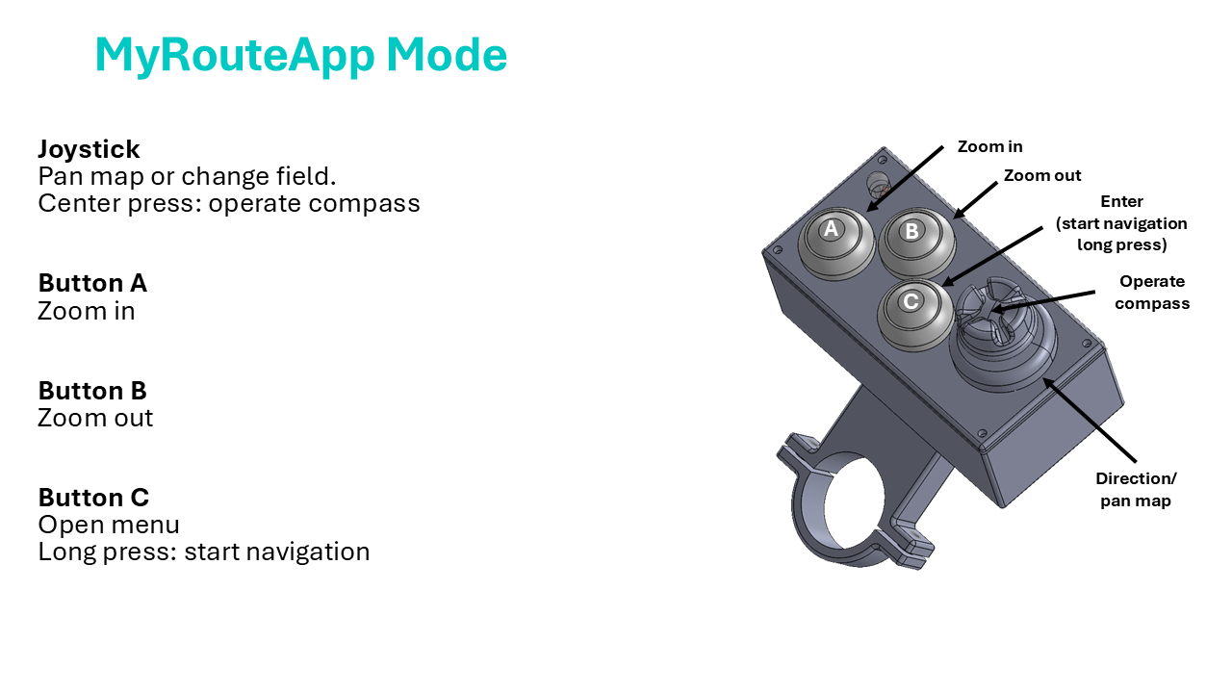
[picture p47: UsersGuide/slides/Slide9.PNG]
Slide 9


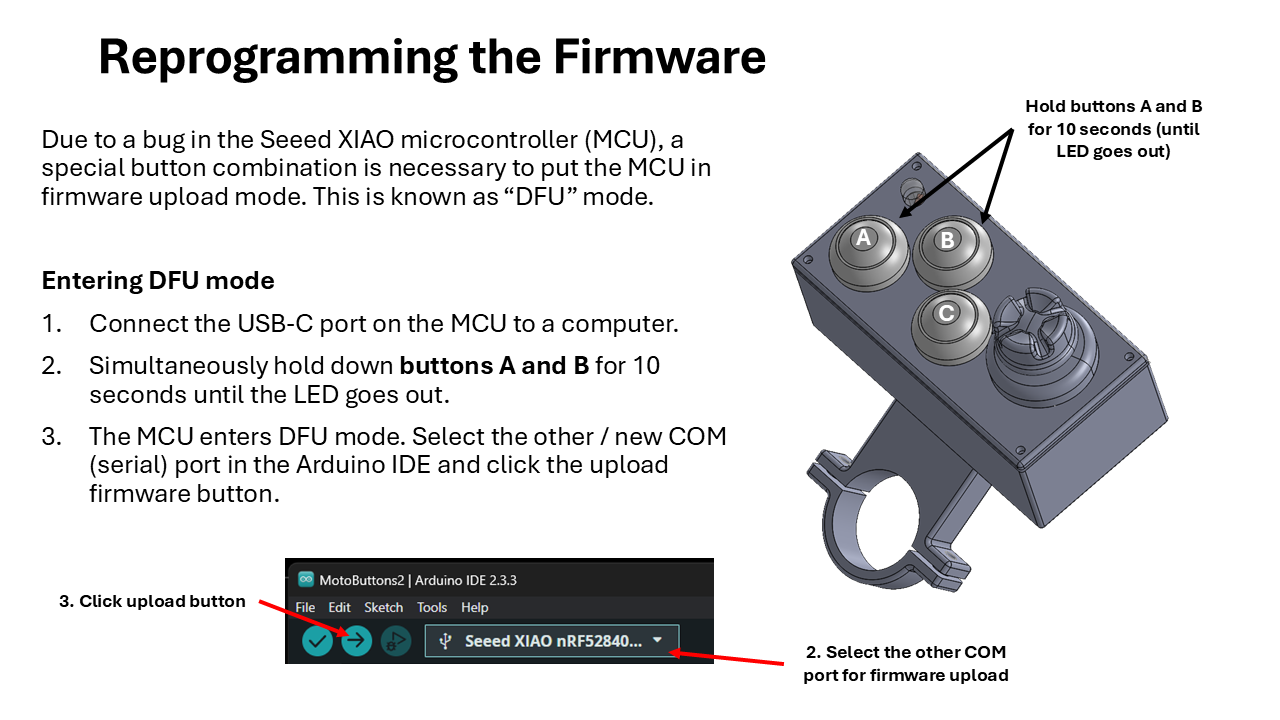
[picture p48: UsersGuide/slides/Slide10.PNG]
Slide 10


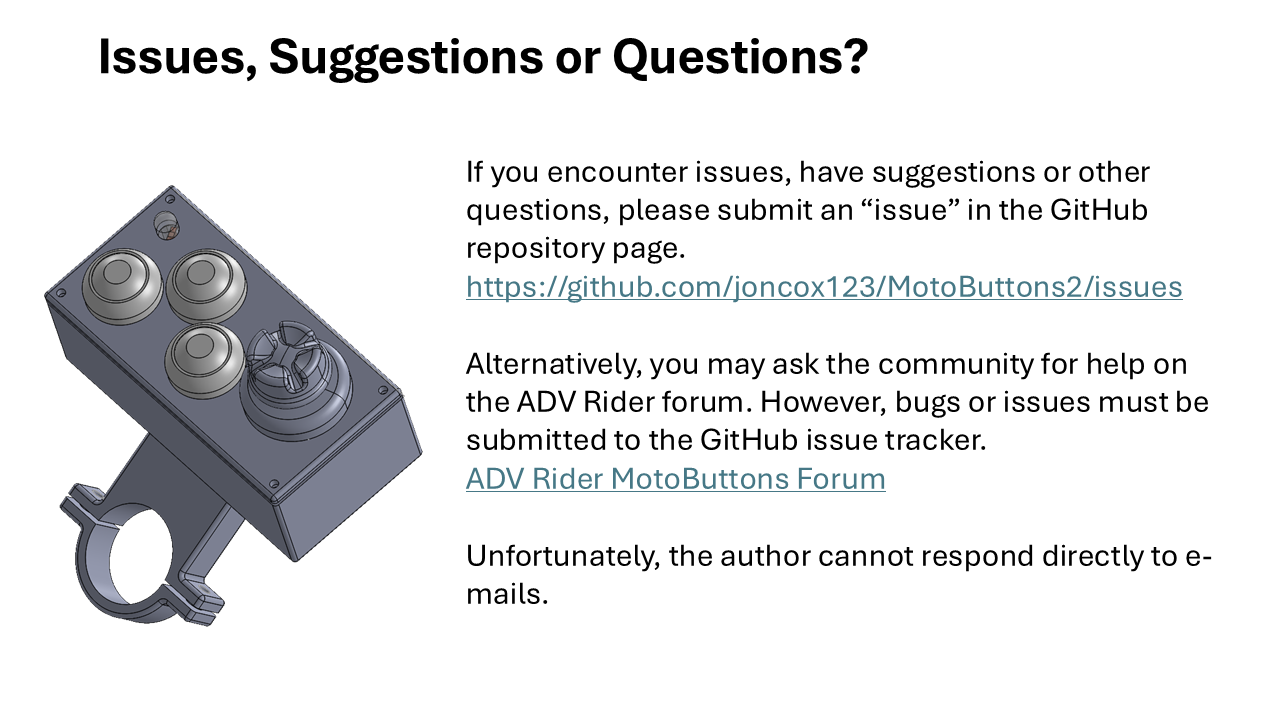
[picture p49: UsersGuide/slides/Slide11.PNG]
Slide 11


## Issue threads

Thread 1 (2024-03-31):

MotoButtons 2

MotoMongrel, 2024-03-31:
Hi Mate,
So happy you're making version 2. I have a Ruffy 4 way and 5 way joystick and was about to solder up your original design, but now I'll wait till you've finished version 2. Would it be possible to create 2 versions of the firmware, one with the 4 way joystick and one for the 5 way, giving an extra junction without taking up any more room in the case? Here is a pic of the two setups I made for MotoButtons 1.
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

It mounts to the left hand rear brake lever.

joncox123, 2024-09-26:
Nice work, I really like your design. Mine is a little more boxy. I will be completing MotoButtons 2 construction and coding this week. In turns out, I got a good deal on a 4-way joystick that is normally $300. So I'll actually be writing the code for a 4-way at first.

Closed 2024-10-06.

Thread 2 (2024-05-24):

Code Update?

MotoMongrel, 2024-05-24:
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
Hi,
Any update on the Code. I've designed 2 options for the cases .

joncox123, 2024-09-26:
Wow, the good work keeps coming. I will be completing the MotoButtons 2 code this week.

MotoMongrel, 2024-09-26:
I ended up going with Razorpad code here on GitHub as it's been a few months with no reply from you. I thought that maybe you'd decided not to continue with it. All good

gasperzupancic, 2024-10-06:
@MotoMongrel can you share the 3d print files maybe?

MotoMongrel, 2024-10-06:
> @MotoMongrel can you share the 3d print files maybe?

It's custom designed to bolt to my left hand rear brake, not the handlebars. Here's a link to what I've done that properly explains better what I've done.   https://www.facebook.com/share/fencRY91Z7r1L4gP/

MotoMongrel, 2024-10-06:
> @MotoMongrel can you share the 3d print files maybe?

I ended up going with the Razorpad firmware on Github. Here is the finished remote
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

joncox123, 2024-10-06:
3D files are already posted on the repo. Check the instructions.

Closed 2024-10-06.

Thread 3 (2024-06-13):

Any Chance of a reply to when code will be ready?

MotoMongrel, 2024-06-13:
Any Chance of a reply to when code will be ready?

joncox123, 2024-09-26:
Hi there, ordered the remaining parts and I will be completing construction and code update this week. I got a good deal on a 4-way industrial hat switch that is normally $300, but other than that the parts will be the same as what is shown in the Bill of Materials (BOM).

Closed 2024-09-26.

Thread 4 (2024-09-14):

3d printing service - I can do it.

downerhouse, 2024-09-14:
When you are ready with your final design, id be happy to discuss a very low cost 3d printing service I can provide for the case. I'd need the CAD files to be able to give an estimate. Pretty sure I'll be a lot cheaper than anyone else - postage is likely to be the highest element of the cost.

joncox123, 2024-09-26:
I had this printed in Nylon SLA via Cloudcraft for only $15. I am not in the business of selling these, it's only an open-source design.

Closed 2024-09-26.

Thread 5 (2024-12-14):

working on a similar project

RE-Specto, 2024-12-14:
pretty neat device that you built here! I"m working on a similar project, but using some [ESP32-BLE](https://github.com/T-vK/ESP32-BLE-Keyboard) libraries. just stumbled upon yours, probably going to construct one for experimenting with, and I guess I would have some ideas. would you be up for some collaboration?

joncox123, 2024-12-17:
Hi, thanks for checking out the project. Unfortunately, I don't have additional time to commit, but I would encourage you to use the resources here or fork the repo. You are also welcome to design improvements and submit merge requests. In particular, better case designs  will be useful.

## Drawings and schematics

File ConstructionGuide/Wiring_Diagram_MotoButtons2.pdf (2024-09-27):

## MotoButtons2 Wiring Diagram

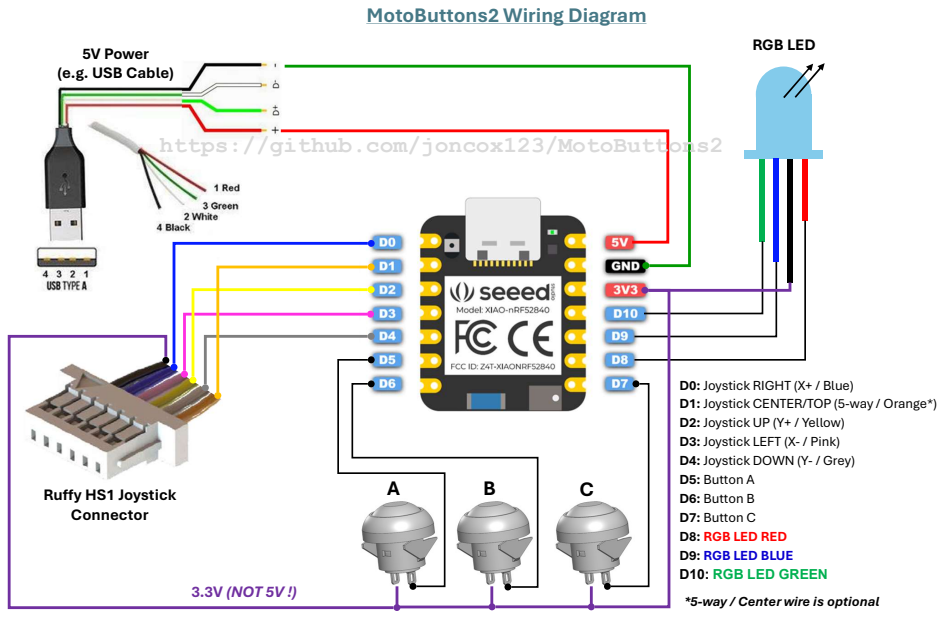
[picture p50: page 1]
3.3V (NOT 5V !); Ruffy HS1 Joystick Connector

RGB LED 5V Power
(e.g. USB Cable)

https://github.com/joncox123/MotoButtons2

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

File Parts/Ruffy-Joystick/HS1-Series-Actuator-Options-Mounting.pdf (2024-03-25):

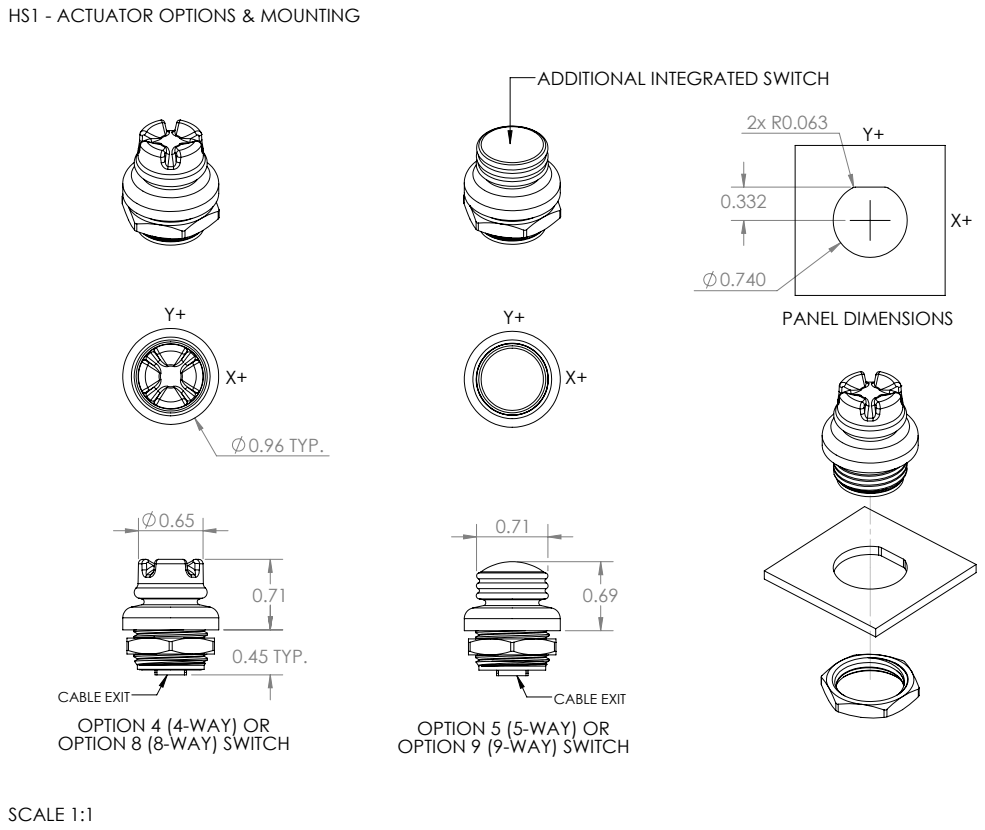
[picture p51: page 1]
CABLE EXIT; 0.45 TYP.; 0.96 TYP.; PANEL DIMENSIONS; SCALE 1:1

HS1 - ACTUATOR OPTIONS & MOUNTING

ADDITIONAL INTEGRATED SWITCH

CABLE EXIT
OPTION 4 (4-WAY) OR
OPTION 8 (8-WAY) SWITCH

OPTION 5 (5-WAY) OR
OPTION 9 (9-WAY) SWITCH

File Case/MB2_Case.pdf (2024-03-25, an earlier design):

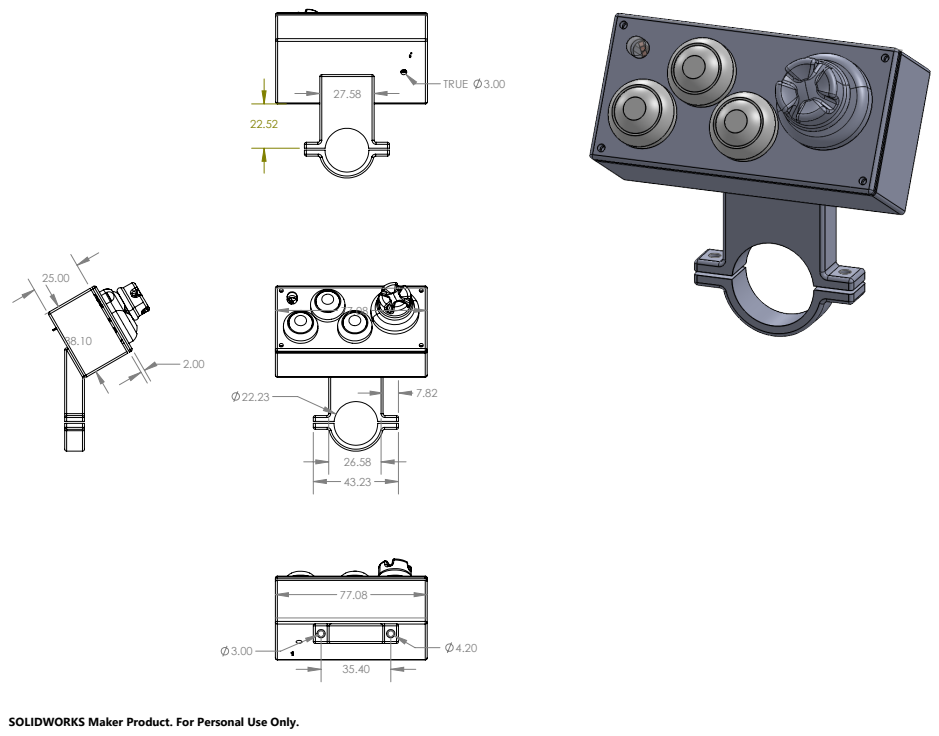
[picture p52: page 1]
TRUE 3.00

SOLIDWORKS Maker Product. For Personal Use Only.

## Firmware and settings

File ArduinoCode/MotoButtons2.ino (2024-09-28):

/*********************************************************************
License: GNU GENERAL PUBLIC LICENSE; Version 3, 29 June 2007
Version: 2.0 with support for the following modes: DMD2, mouse cursor, MyRoute App, media (music)
Device: Seeed XIAO nRF52840 (MotoButtons 2)
*********************************************************************/
#include <bluefruit.h>
#include <Adafruit_LittleFS.h>
#include <InternalFileSystem.h>
#include <Adafruit_TinyUSB.h>
#include <stdlib.h>

using namespace Adafruit_LittleFS_Namespace;

// Enable serial debugging (turn this off if not connected to PC)
#define DEBUG false

// How long to wait until DFU reset mode is activated
#define MODE_RESET_MS 10000

// Orientation of controller
#define DEFAULT_BUTTON_MAP 0
uint8_t buttonOrientation = DEFAULT_BUTTON_MAP;

// how long to deactivate physical button after virtual button is released
#define BUTTON_VIRTUAL_TIMEOUT 500 // ms

/*----- Persistent Storage Filesystem -----*/
// This is used to store settings, such as the last mode
#define FILENAME "/MotoButtons.set"
File file(InternalFS);

// BLE classes
BLEDis bledis;
BLEHidAdafruit blehid;

// BLE configuration
#define BLE_TX_POWER 8
const char BLE_DEVICE_NAME[] = "DMD2 CTL 8K";
const char BLE_DEVICE_MODEL[] = "MotoButtons 2.0";
const char BLE_MANUFACTURER[] = "Me";
bool BLE_connected = false;

// RGB LED colors plus off
typedef enum
{
  Red,     // virtual button activated
  Blue,    // BLE connected (flashing, BLE not connected)
  Green,   // mouse mode
  Yellow,  // DMD2 mode
  Cyan,    // MRA mode
  Magenta, // media mode
  White,   // regular key press
  Off,
} Color;

Color priorLEDState = Off;
Color LEDState = Off;

#define VIRT_BUTT_COLOR Red
#define BLE_COLOR Blue
#define MOUSE_MODE_COLOR Green
#define DMD2_MODE_COLOR Yellow
#define MRA_MODE_COLOR Cyan
#define MEDIA_MODE_COLOR Magenta
#define KEY_PRESS_COLOR White
#define POWER_ON_COLOR Red
#define SETUP_COMPLETE_COLOR White
#define BUTTON_ORIENTATION_COLOR Red

/*
 * --------------------- MODE CONFIGURATION ----------------------------
 * 	DMD2: up/down/left/right arrows, enter, F6 and F7
 * 	Mouse: mouse up/down/left/right, left click, left click, ?
 * 	MyRouteApp: up/down/left/right arrows, 'c', -, +, longpress center for 'n' (hold center for skip waypoint)
 *  Media (music): vol up, vol down, previous track, next track, mute, play/pause, stop
 */
// Selected Mode: indicates the currently selected operating mode
#define MODE_TOGGLE_MS 1000
#define N_MODES 4
typedef enum
{
  Mouse = 0,
  DMD2 = 1,
  MRA = 2,
  MEDIA = 3
} Mode;
Mode currentMode;

bool modeButtonsReleased = true;

// how long we must hold a physical button before the virtual function is activated
#define VIRT_BUTT_HOLD_DURATION 1000

/* DMD2 Mode Configuration */
// https://www.drivemodedashboard.com/controller-implementation-guide/
// https://arduino.stackexchange.com/questions/65513/how-do-i-send-non-ascii-keys-over-the-ble-hid-connection-using-an-adafruit-nrf52
// https://github.com/adafruit/Adafruit_nRF52_Arduino/blob/200b3aaefb3256ac26df82ebc9b5b58923d9c37c/cores/nRF5/Adafruit_TinyUSB_Core/tinyusb/src/class/hid/hid.h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
// https://github.com/adafruit/Adafruit_nRF52_Arduino/issues/785
// Key codes to send for button presses:
const uint8_t DMD_KEY_UP = HID_KEY_ARROW_UP;
const uint8_t DMD_KEY_DOWN = HID_KEY_ARROW_DOWN;
const uint8_t DMD_KEY_LEFT = HID_KEY_ARROW_LEFT;
const uint8_t DMD_KEY_RIGHT = HID_KEY_ARROW_RIGHT;
const uint8_t DMD_KEY_CENTER = HID_KEY_ENTER;
const uint8_t DMD_KEY_A = HID_KEY_F6;
const uint8_t DMD_KEY_B = HID_KEY_F7;
const uint8_t DMD_KEY_C = HID_KEY_ENTER;
const uint8_t DMD_KEY_VIRTUAL = HID_KEY_F5;

/* Mouse Mode Configuration */
#define MOUSE_RATE_SLOW 5
#define MOUSE_RATE_FAST 20
#define MOUSE_RATE_DELAY 500
bool mouse_left_button_pressed = false;
const uint8_t MOUSE_KEY_A = HID_KEY_BACKSPACE;
const uint8_t MOUSE_KEY_B = HID_KEY_ENTER;

/* MyRouteApp Mode Configuration */
const uint8_t MRA_KEY_UP = HID_KEY_ARROW_UP;
const uint8_t MRA_KEY_DOWN = HID_KEY_ARROW_DOWN;
const uint8_t MRA_KEY_LEFT = HID_KEY_ARROW_LEFT;
const uint8_t MRA_KEY_RIGHT = HID_KEY_ARROW_RIGHT;
const uint8_t MRA_KEY_CENTER = HID_KEY_C;     // operate compass
const uint8_t MRA_KEY_A = HID_KEY_KEYPAD_ADD; // zoom in
const uint8_t MRA_KEY_B = HID_KEY_MINUS;      // zoom out
const uint8_t MRA_KEY_C = HID_KEY_N;          // open menu
const uint8_t MRA_KEY_VIRTUAL = HID_KEY_D;    // start navigation

/* Media Mode Configuration */
const uint8_t MEDIA_KEY_UP = HID_USAGE_CONSUMER_VOLUME_INCREMENT;    // volume up
const uint8_t MEDIA_KEY_DOWN = HID_USAGE_CONSUMER_VOLUME_DECREMENT;  // volume down
const uint8_t MEDIA_KEY_LEFT = HID_USAGE_CONSUMER_SCAN_PREVIOUS;     // previous song
const uint8_t MEDIA_KEY_RIGHT = HID_USAGE_CONSUMER_SCAN_NEXT;        // next song
const uint8_t MEDIA_KEY_CENTER = HID_USAGE_CONSUMER_MUTE;            // Mute
const uint8_t MEDIA_KEY_A = HID_USAGE_CONSUMER_PLAY_PAUSE;           // play - pause
const uint8_t MEDIA_KEY_B = HID_USAGE_CONSUMER_STOP;                 // stop music
const uint8_t MEDIA_KEY_C = HID_USAGE_CONSUMER_BRIGHTNESS_INCREMENT; // increase brightness
const uint8_t MEDIA_KEY_VIRTUAL = HID_USAGE_CONSUMER_MUTE;           // Mute
/*---------------------- END MODE CONFIGURATION ----------------------*/

/*----------------- BUTTON CONFIGURATION AND LOGIC -------------------*/
/* BLE key report */
#define N_KEY_REPORT 6
uint8_t keyReport[N_KEY_REPORT] = {HID_KEY_NONE, HID_KEY_NONE, HID_KEY_NONE, HID_KEY_NONE, HID_KEY_NONE, HID_KEY_NONE};
bool keyReportChanged = false;
bool forceKeyReport = false; // used to force another key report for key up activation events

// Digital IO pin mapping (default)
uint8_t BUTTON_UP = 4;
uint8_t BUTTON_DOWN = 2;
uint8_t BUTTON_LEFT = 0;
uint8_t BUTTON_RIGHT = 3;
uint8_t BUTTON_CENTER = 1;
uint8_t BUTTON_A = 5;
uint8_t BUTTON_B = 6;
uint8_t BUTTON_C = 7;
uint8_t RGB_LED_RED = 8;
uint8_t RGB_LED_BLUE = 9;
uint8_t RGB_LED_GREEN = 10;

#define DEBOUNCE_TIME_MS 50

// state of buttons
bool button_up_state = false;
bool button_down_state = false;
bool button_left_state = false;
bool button_right_state = false;
bool button_center_state = false;
bool button_A_state = false;
bool button_B_state = false;
bool button_C_state = false;
bool button_virtual_state = false; // 8th virtual button activated via long press

// prior state of button reading for debouncing purposes
bool button_up_state_prior = false;
bool button_down_state_prior = false;
bool button_left_state_prior = false;
bool button_right_state_prior = false;
bool button_center_state_prior = false;
bool button_A_state_prior = false;
bool button_B_state_prior = false;
bool button_C_state_prior = false;

// Record state change of buttons to be used to monitor when event is transmitted
bool button_up_flipped = false;
bool button_down_flipped = false;
bool button_left_flipped = false;
bool button_right_flipped = false;
bool button_center_flipped = false;
bool button_A_flipped = false;
bool button_B_flipped = false;
bool button_C_flipped = false;
bool button_virtual_flipped = false;

// a flag to indicate that virtual button was released, for center timeout purposes only
bool button_virtual_timeout = false;

// last time that button transitioned from low to high
unsigned long button_up_time = 0;
unsigned long button_down_time = 0;
unsigned long button_left_time = 0;
unsigned long button_right_time = 0;
unsigned long button_center_time = 0;
unsigned long button_A_time = 0;
unsigned long button_B_time = 0;
unsigned long button_C_time = 0;
unsigned long button_virtual_time = 0;
/*------------------- END BUTTON CONFIG & LOGIC-----------------------*/

/*
  Set the color of the RGB LED to one of the 7 possibilities, plus off
  For a common anode(+) LED, LOW is ON and HIGH is OFF.
*/
void setRGBColor(Color color)
{
  priorLEDState = LEDState;

  switch (color)
  {
  case Red:
    LEDState = Red;
    digitalWrite(RGB_LED_RED, LOW);
    digitalWrite(RGB_LED_BLUE, HIGH);
    digitalWrite(RGB_LED_GREEN, HIGH);
    break;
  case Blue:
    LEDState = Blue;
    digitalWrite(RGB_LED_RED, HIGH);
    digitalWrite(RGB_LED_BLUE, LOW);
    digitalWrite(RGB_LED_GREEN, HIGH);
    break;
  case Green:
    LEDState = Green;
    digitalWrite(RGB_LED_RED, HIGH);
    digitalWrite(RGB_LED_BLUE, HIGH);
    digitalWrite(RGB_LED_GREEN, LOW);
    break;
  case Yellow:
    LEDState = Yellow;
    digitalWrite(RGB_LED_RED, LOW);
    digitalWrite(RGB_LED_BLUE, HIGH);
    digitalWrite(RGB_LED_GREEN, LOW);
    break;
  case Cyan:
    LEDState = Cyan;
    digitalWrite(RGB_LED_RED, HIGH);
    digitalWrite(RGB_LED_BLUE, LOW);
    digitalWrite(RGB_LED_GREEN, LOW);
    break;
  case Magenta:
    LEDState = Magenta;
    digitalWrite(RGB_LED_RED, LOW);
    digitalWrite(RGB_LED_BLUE, LOW);
    digitalWrite(RGB_LED_GREEN, HIGH);
    break;
  case White:
    LEDState = White;
    digitalWrite(RGB_LED_RED, LOW);
    digitalWrite(RGB_LED_BLUE, LOW);
    digitalWrite(RGB_LED_GREEN, LOW);
    break;
  case Off:
  default:
    LEDState = Off;
    digitalWrite(RGB_LED_RED, HIGH);
    digitalWrite(RGB_LED_BLUE, HIGH);
    digitalWrite(RGB_LED_GREEN, HIGH);
  }
}

void flashLED(Color color, uint16_t delayMs, uint16_t durationMs)
{
  uint8_t N = durationMs / delayMs;

  priorLEDState = LEDState;
  LEDState = color;

  for (uint8_t i = 0; i < 2 * (N + 1); i++)
  {
    if (i % 2 == 0)
      setRGBColor(Off);
    else
      setRGBColor(color);
    delay(delayMs / 2);
  }
}

void restoreLEDState()
{
  setRGBColor(priorLEDState);
  LEDState = priorLEDState;
}

void indicateMode(Mode mode)
{
  // Indicate the new mode
  switch (mode)
  {
  case Mouse:
    flashLED(MOUSE_MODE_COLOR, 1000, 200);
    setRGBColor(MOUSE_MODE_COLOR);
    break;
  case DMD2:
    flashLED(DMD2_MODE_COLOR, 1000, 200);
    setRGBColor(DMD2_MODE_COLOR);
    break;
  case MRA:
    flashLED(MRA_MODE_COLOR, 1000, 200);
    setRGBColor(MRA_MODE_COLOR);
    break;
  case MEDIA:
    flashLED(MEDIA_MODE_COLOR, 1000, 200);
    setRGBColor(MEDIA_MODE_COLOR);
    break;
  default:
    setRGBColor(Red);
  }
}

void showMode(Mode mode)
{
  // Indicate the new mode
  switch (mode)
  {
  case Mouse:
    setRGBColor(MOUSE_MODE_COLOR);
    break;
  case DMD2:
    setRGBColor(DMD2_MODE_COLOR);
    break;
  case MRA:
    setRGBColor(MRA_MODE_COLOR);
    break;
  case MEDIA:
    setRGBColor(MEDIA_MODE_COLOR);
    break;
  default:
    setRGBColor(Red);
  }
}

void RGBToggle(Color color)
{
  bool ledIsOn = !digitalRead(RGB_LED_RED) || !digitalRead(RGB_LED_BLUE) || !digitalRead(RGB_LED_GREEN);

  if (ledIsOn)
    setRGBColor(Off);
  else
    setRGBColor(color);
}

// cycle through all colors of the LED for demo purposes
void colorCycle(uint16_t N)
{
  for (uint32_t i = 0; i < N * 7; i++)
  {
    setRGBColor((Color)(i % 7));
    delay(500);
  }
}

// At startup, the user can hold down a joystick direction to select an orientation
// -1 indicates no valid selection was made
int getButtonMapSelection()
{
  // Read all four directions because we can only allow a mode switch if
  // one direction is pressed
  uint8_t up = digitalRead(BUTTON_UP);
  uint8_t down = digitalRead(BUTTON_DOWN);
  uint8_t left = digitalRead(BUTTON_LEFT);
  uint8_t right = digitalRead(BUTTON_RIGHT);

  if (up + down + left + right > 1)
  {
    // user held down more than one direction, return the default mapping
    return -1;
  }

  if (up)
    return 2;
  if (down)
    return 0;
  if (left)
    return 1;
  if (right)
    return 3;

  // no selection was made
  return -1;
}

/* Change the mapping of buttons based on a map specifier, buttMap
 * butMapp:
 * 	0: UP is GPIO pin 2
 *  1: UP is GPIO pin 3
 *  2: UP is GPIO pin 4
 *  3: UP is GPIO pin 0
 */
bool setButtonMapping(uint8_t buttMap)
{
  switch (buttMap)
  {
  case 0: // three buttons on top
    BUTTON_UP = 2;
    BUTTON_DOWN = 4;
    BUTTON_LEFT = 3;
    BUTTON_RIGHT = 0;
    BUTTON_CENTER = 1;
    BUTTON_A = 5;
    BUTTON_B = 6;
    BUTTON_C = 7;
    break;
  case 1: // three buttons on left
    BUTTON_UP = 0;
    BUTTON_DOWN = 3;
    BUTTON_LEFT = 2;
    BUTTON_RIGHT = 4;
    BUTTON_CENTER = 1;
    BUTTON_A = 5;
    BUTTON_B = 6;
    BUTTON_C = 7;
    break;
  case 2: // three buttons on bottom
    BUTTON_UP = 4;
    BUTTON_DOWN = 2;
    BUTTON_LEFT = 0;
    BUTTON_RIGHT = 3;
    BUTTON_CENTER = 1;
    BUTTON_A = 5;
    BUTTON_B = 6;
    BUTTON_C = 7;
    break;
  case 3: // three buttons toward right
    BUTTON_UP = 3;
    BUTTON_DOWN = 0;
    BUTTON_LEFT = 4;
    BUTTON_RIGHT = 2;
    BUTTON_CENTER = 1;
    BUTTON_A = 5;
    BUTTON_B = 6;
    BUTTON_C = 7;
    break;
  default:
    return true;
  }

  return false;
}

// This function returns true if the center button is in an active state
// if so, the program should ignore up/down/left/right on the joystick
bool isCenterActive()
{
  if (button_center_state)
    return true;
  if (digitalRead(BUTTON_CENTER))
    return true;

  return false;
}

bool isVirtualActive()
{
  if (millis() - button_virtual_time < BUTTON_VIRTUAL_TIMEOUT)
    return true;

  return button_virtual_state;
}

// if  This function should be called rapidly in a loop to update the debounce filter and key state
//  https://docs.arduino.cc/built-in-examples/digital/Debounce
bool debounceButton(unsigned int button, bool *state, bool *priorState, bool *buttonFlipped,
                    unsigned long *debounceTime, const char *buttonName)
{
  bool reading;
  unsigned long readTime;
  bool stateChanged = false;

  reading = digitalRead(button);
  readTime = millis();

  // If reading has changed, switch has not settled yet
  if (reading != *priorState)
    *debounceTime = readTime;
  // State has been stable for time exceeding debounce filter delay, so update state
  else if ((readTime - *debounceTime) > DEBOUNCE_TIME_MS)
    // If state changed after debounce, new state has not yet been transmitted
    if (reading != *state)
    {
      stateChanged = true;
      *state = reading;
      *buttonFlipped = true;
    }
  *priorState = reading;

  return stateChanged;
}

void releaseAllKeys()
{
  uint8_t keyReportRelease[N_KEY_REPORT] = {HID_KEY_NONE, HID_KEY_NONE, HID_KEY_NONE, HID_KEY_NONE, HID_KEY_NONE, HID_KEY_NONE};
  blehid.keyboardReport(0, keyReportRelease);
}

void updateButtons()
{
  bool stateChanged = false;

  // Read the state of all physical buttons
  stateChanged |= debounceButton(BUTTON_UP, &button_up_state, &button_up_state_prior, &button_up_flipped, &button_up_time, "UP");
  stateChanged |= debounceButton(BUTTON_DOWN, &button_down_state, &button_down_state_prior, &button_down_flipped, &button_down_time, "DOWN");
  stateChanged |= debounceButton(BUTTON_LEFT, &button_left_state, &button_left_state_prior, &button_left_flipped, &button_left_time, "LEFT");
  stateChanged |= debounceButton(BUTTON_RIGHT, &button_right_state, &button_right_state_prior, &button_right_flipped, &button_right_time, "RIGHT");
  stateChanged |= debounceButton(BUTTON_CENTER, &button_center_state, &button_center_state_prior, &button_center_flipped, &button_center_time, "CENTER");
  stateChanged |= debounceButton(BUTTON_A, &button_A_state, &button_A_state_prior, &button_A_flipped, &button_A_time, "A");
  stateChanged |= debounceButton(BUTTON_B, &button_B_state, &button_B_state_prior, &button_B_flipped, &button_B_time, "B");
  stateChanged |= debounceButton(BUTTON_C, &button_C_state, &button_C_state_prior, &button_C_flipped, &button_C_time, "C");

  /* ----------- Detect state of virtual press for Button C ---------------------*/
  if (button_C_state && (millis() - button_C_time > VIRT_BUTT_HOLD_DURATION))
  {
    // virtual button activated
    if (!button_virtual_state)
    {
      if (DEBUG)
        Serial.println("Virtual button C activated.");
      button_virtual_time = millis();
      button_virtual_flipped = true;
      stateChanged |= true;

      // indicate virtual button
      setRGBColor(VIRT_BUTT_COLOR);
    }
    button_virtual_state = true;
  }
  else if (button_virtual_state)
  {
    // virtual button is not active
    button_virtual_flipped = true;
    button_virtual_state = false;
    button_virtual_timeout = true;
    button_virtual_time = millis();
    if (DEBUG)
      Serial.println("Virtual button C deactivated, timeout enabled.");
    showMode(currentMode);
    stateChanged |= true;
  }

  // Also, a race condition can occur where the virtual button is released and the physical button flips from high to low, activating the physical button
  // Therefore, the release action of the virtual button is to disable the physical button for a period of time
  if (button_virtual_timeout)
    button_C_flipped = false;
  if (button_virtual_timeout && (millis() - button_virtual_time > BUTTON_VIRTUAL_TIMEOUT))
  {
    button_virtual_timeout = false;
    if (DEBUG)
      Serial.println("Virtual button C timeout disabled.");
  }

  /*------------------------------------------------------------------*/

  // Indicate whether any buttons changed state
  keyReportChanged = stateChanged;

  /* Hard reset and enter firmware udpate mode (DFU)
   * This mode is necessary because the bootloader in the Seed nRF52840 has a bug that prevents uploading new software
   * from the Arduino IDE if a BLE sketch is uploaded previously. Thus, it is necessary to enter via triggering a DFU reset event.
   */
  if (button_A_state && button_B_state && (millis() - button_A_time > MODE_RESET_MS) && (millis() - button_B_time > MODE_RESET_MS))
  {
    if (DEBUG)
      Serial.println("Resetting and entering firmware update (FDU) mode...");
    enterSerialDfu();
  }

  /*------------------- Handle mode cycling --------------------------*/
  // Check for release of mode cycle button combination
  if (!button_A_state || !button_B_state)
  {
    modeButtonsReleased = true;
  }

  if (button_A_state && button_B_state && (millis() - button_A_time > MODE_TOGGLE_MS) && (millis() - button_B_time > MODE_TOGGLE_MS) && modeButtonsReleased)
  {
    // Buttons A and B were both long-pressed, which means we should advance the mode
    currentMode = (Mode)(((int)currentMode + 1) % N_MODES);
    if (DEBUG)
    {
      Serial.print("Mode advanced to ");
      Serial.println(currentMode);
    }

    // Since mode has been changed, inactivate any ongoing key or mouse presses
    releaseAllKeys();
    blehid.mouseButtonRelease();
    modeButtonsReleased = false;

    // store new mode to flash memory
    writeSettings();

    indicateMode(currentMode);
  }
  /*------------------------------------------------------------------*/
}
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
void loop()
{
  // Indicate whether the device is connected and running
  if (!BLE_connected && (Bluefruit.connected() > 0))
  {
    if (DEBUG)
      Serial.println("BLE connected to host.");
    showMode(currentMode);
    BLE_connected = true;
  }
  else if (Bluefruit.connected() == 0)
  {
    RGBToggle(BLE_COLOR);
    delay(200);
    BLE_connected = false;
  }

  // Read current state of buttons
  updateButtons();

  if (BLE_connected)
  {
    // Compile the BLE HID key report
    if (keyReportChanged || forceKeyReport)
    {
      if (forceKeyReport) {
        forceKeyReport = false;
        if (DEBUG)
          Serial.println("Key report forced.");
      }
      mapButtonsToKeyReport();
      blehid.keyboardReport(0, keyReport);
      if (DEBUG)
        Serial.println("Key report sent.");
    }

    if (currentMode == Mouse)
      handleMouse();
  }
}

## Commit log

2024-03-25 added initial 3d printed case design
    [MB2_Case.SLDASM, MB2_Case.STEP, case-bottom.SLDPRT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]
2024-03-25 Parts specifications, models and updated case info
    [BOM.xlsx, HS1-48.IGS, MB2_Case.SLDASM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]
2024-03-25 updated case
    [MB2_Case.SLDASM, MB2_Case.SLDDRW, MB2_Case.STEP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]
2024-03-28 Initial 3D print
    MB2_v1.0, SLS Nylon PA12
    [MB2_Case.SLDASM, MB2_Case.SLDDRW, MB2_Case.STEP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]
2024-09-28 Update MotoButtons2.ino
    need to rework the button pressing action and virtual button action
    [MotoButtons2.ino]
